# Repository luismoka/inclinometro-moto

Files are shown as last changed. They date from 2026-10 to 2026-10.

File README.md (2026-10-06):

# Inclinómetro para moto (MotoLean)

**Versión 3.2**

> **Nuevo:** versión para la placa Waveshare ESP32-S3-LCD-1.69 (pantalla de 1,69"), todavía sin probar en placa real. Ver [docs/PLACA_169.md](docs/PLACA_169.md). El resto de este documento describe la versión para la LOLIN S3 Mini Pro (firmware 2.3).

Inclinómetro casero para moto basado en una placa **LOLIN S3 Mini Pro** (ESP32-S3 con pantalla de 0,85" y sensor de movimiento integrado) y un GPS **NEO-6M**. Muestra la inclinación, la aceleración y la velocidad, graba las rutas y las enseña después sobre un mapa.

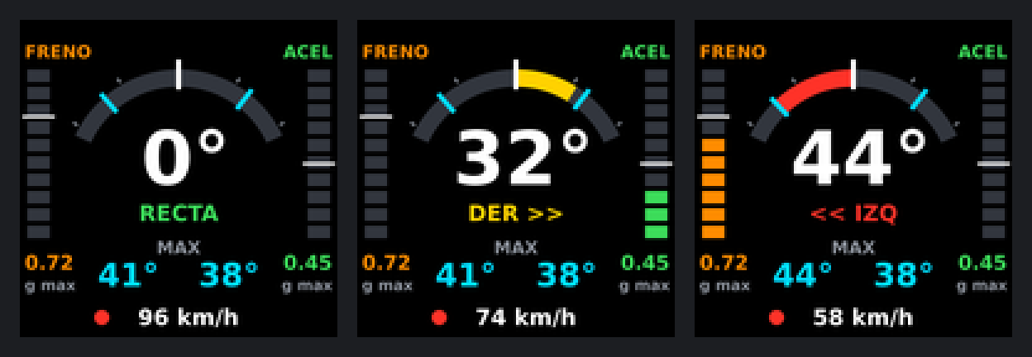
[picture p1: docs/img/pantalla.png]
Pantalla del inclinómetro


## Qué hace

- **Inclinación en directo**, con arco de color: azul hasta 25°, amarillo hasta 40°, rojo a partir de ahí.
- **Máxima inclinación** a izquierda y derecha.
- **Aceleración y frenada** en g, con barra en directo y máximo alcanzado.
- **Velocidad GPS** en pantalla y velocidad máxima.
- **Grabación de rutas**: posición, velocidad, inclinación, aceleración y frenada, un punto por segundo.
- **Mapa**: la ruta se ve después coloreada por inclinación o velocidad, con las frenadas y los acelerones marcados.
- **Web propia**: datos en directo, descarga de rutas y configuración desde el móvil o el ordenador, sin instalar ninguna app.
- **WiFi de casa**: en casa se une a la red doméstica y se entra en `http://motolean.local`.
- **Memoria**: máximos, calibración y rutas se conservan al apagar.
- **Montaje libre**: una calibración de dos pasos permite colocar la placa en cualquier posición.
- **Caja desmontable**: la base se queda en la moto y la electrónica se quita y se pone sin herramientas.

Sin GPS el inclinómetro funciona igual, sin velocidad ni rutas, y no hace falta soldar nada.

## Novedades de la versión 2.0

| Novedad | Dónde se explica |
|---|---|
| GPS: velocidad y grabación de rutas | [docs/GPS_Y_RUTAS.md](docs/GPS_Y_RUTAS.md) |
| Página de mapa para ver las rutas | [docs/WEB.md](docs/WEB.md) |
| Web ampliada: rutas y WiFi de casa | [docs/WEB.md](docs/WEB.md) |
| Caja desmontable con GPS | [docs/CAJA_GPS.md](docs/CAJA_GPS.md) |
| Pulsadores para la tapa | [docs/SOPORTE.md](docs/SOPORTE.md) |
| Cajas ajustadas con medidas de calibre | [docs/SOPORTE.md](docs/SOPORTE.md) |

El detalle completo está en el [CHANGELOG.md](CHANGELOG.md).

## Puesta en marcha

1. **Reunir el material**: [docs/MATERIALES.md](docs/MATERIALES.md).
2. **Cargar el firmware** ya compilado desde el navegador: [docs/CARGAR_FIRMWARE.md](docs/CARGAR_FIRMWARE.md).
3. **Soldar el GPS** (opcional): [docs/GPS_Y_RUTAS.md](docs/GPS_Y_RUTAS.md).
4. **Imprimir y montar la caja**: [docs/CAJA_GPS.md](docs/CAJA_GPS.md) con GPS, o [docs/SOPORTE.md](docs/SOPORTE.md) sin él.
5. **Calibrar y usar**: [docs/USO.md](docs/USO.md).

## Documentación

| Documento | Contenido |
|---|---|
| [docs/MATERIALES.md](docs/MATERIALES.md) | Lista de todo lo que se utiliza: componentes, tornillería, herramientas y programas |
| [docs/CARGAR_FIRMWARE.md](docs/CARGAR_FIRMWARE.md) | Cómo grabar el `.bin` en la placa sin instalar nada |
| [docs/USO.md](docs/USO.md) | Botones, calibración y pantalla |
| [docs/WEB.md](docs/WEB.md) | Páginas web de la placa y página del mapa |
| [docs/GPS_Y_RUTAS.md](docs/GPS_Y_RUTAS.md) | Conexión del GPS, grabación de rutas y WiFi de casa |
| [docs/CAJA_GPS.md](docs/CAJA_GPS.md) | Caja desmontable con GPS: base fija y módulo de quita y pon |
| [docs/SOPORTE.md](docs/SOPORTE.md) | Soporte sencillo sin GPS y pulsadores |
| [docs/FUNCIONAMIENTO.md](docs/FUNCIONAMIENTO.md) | Cómo se calcula la inclinación y qué limitaciones tiene |
| [docs/HARDWARE.md](docs/HARDWARE.md) | Pines y componentes de la placa |
| [docs/COMPILAR.md](docs/COMPILAR.md) | Cómo compilar el programa desde el código fuente |
| [CHANGELOG.md](CHANGELOG.md) | Historial de versiones |

## Estructura del repositorio

```
firmware/
  moto_inclinometro/   Código fuente (Arduino)
  bin/                 Firmware compilado, listo para grabar
soporte/               STL de las cajas y scripts que los generan
mapa/                  Página para ver una ruta grabada sobre el mapa
herramientas/          Scripts que generan las imágenes de la documentación
docs/                  Documentación e imágenes
```

## Estado del proyecto

| Parte | Estado |
|---|---|
| Inclinación, aceleración y pantalla | Cargado y funcionando en la placa. Pendiente de probar en marcha |
| GPS, rutas y WiFi de casa | Compilado; **sin probar** con el GPS conectado |
| Página del mapa | Probada con una ruta inventada; el fondo de mapa está pendiente de confirmar |
| Soporte sencillo (sin GPS) | Primera versión impresa; la versión corregida con medidas de calibre está sin imprimir |
| Caja desmontable con GPS | Diseñada; **sin imprimir** |
| Medida del manillar | Calculada (tubo de 28,6 mm), sin medir en la moto |

## Aviso de seguridad

Es un proyecto de aficionado y la medida es orientativa. No mires la pantalla en plena curva ni la uses como referencia para apurar la inclinación.

## Apoyar el proyecto

El proyecto es libre y gratuito. Si te ha sido útil y quieres invitarme a un café, puedes hacerlo en [paypal.me/luismoka](https://paypal.me/luismoka).

## Licencia

Proyecto publicado bajo licencia [MIT](LICENSE).

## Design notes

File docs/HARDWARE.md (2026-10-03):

# Hardware

## Placa: LOLIN S3 Mini Pro v1.1.0

| Característica | Valor |
|---|---|
| Microcontrolador | ESP32-S3FH4R2 (4 MB de flash, 2 MB de PSRAM) |
| Pantalla | TFT de 0,85", 128 × 128, ST7789 (existe otra versión con GC9A01) |
| Sensor de movimiento | QMI8658C, 6 ejes, por I2C |
| Botones | 3 |
| Medidas | 34,3 × 25,4 mm |
| Alimentación | 5 V por USB-C o por el pin 5V |

## Pines usados

| Función | Pin |
|---|---|
| I2C SDA | IO12 |
| I2C SCL | IO11 |
| Dirección I2C del sensor | `0x6B` |
| GPS: TX del módulo | IO13 |
| GPS: RX del módulo | IO14 |
| LED de colores: datos / alimentación | IO8 / IO7 |
| Botón azul | IO0 |
| Botón naranja | IO47 |
| Botón verde | IO48 |
| Pantalla: retroiluminación | IO33 |
| Pantalla: MOSI / SCK | IO38 / IO40 |
| Pantalla: CS / DC / RST | IO35 / IO36 / IO34 |

Los pines de la pantalla los fija la librería TFT_eSPI de WEMOS (archivo `Setup406_LOLIN_S3_MINI_PRO_ST7789.h`).

## Referencias

- [Documentación oficial de la S3 Mini Pro](https://www.wemos.cc/en/latest/s3/s3_mini_pro.html)
- [Ejemplo Arduino oficial](https://github.com/wemos/D1_mini_Examples/tree/master/examples/06.S3_MINI_PRO/s3_mini_pro)
- [TFT_eSPI de WEMOS](https://github.com/wemos/TFT_eSPI)

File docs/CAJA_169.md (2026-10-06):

# Caja para la placa Waveshare ESP32-S3-LCD-1.69

Caja desmontable para la placa de 1,69", el GPS con su antena y la botonera de dos botones. **Primera versión: todavía no se ha impreso ni probado.**

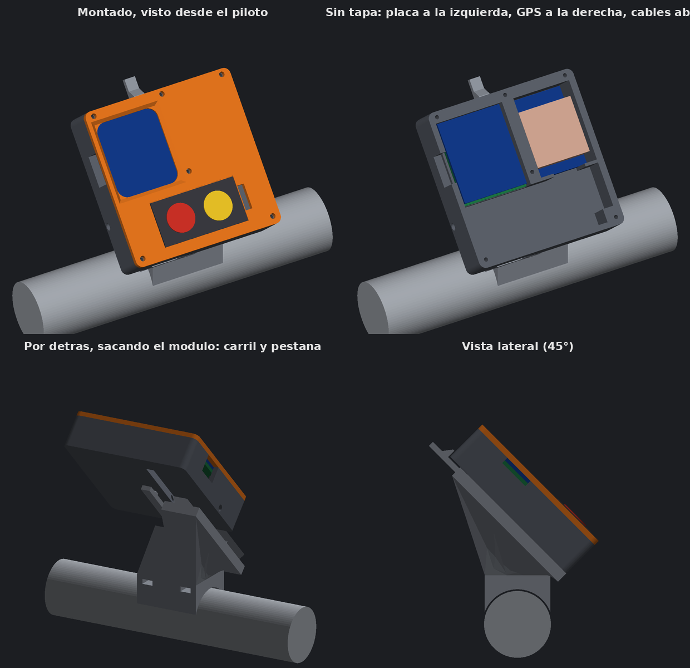
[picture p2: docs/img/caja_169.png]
Caja


## Piezas

| Archivo | Pieza | Cómo imprimirla |
|---|---|---|
| `soporte/caja_169/caja169_base.stl` | Base fija al manillar, con carril y pestaña | Como viene, con el carril hacia arriba; necesita soportes bajo el cuello |
| `soporte/caja_169/caja169_modulo.stl` | Módulo con placa, GPS y cables | Apoyado sobre su trasera, sin soportes |
| `soporte/caja_169/caja169_tapa.stl` | Tapa con ventana y asiento de la botonera | Con la cara interior sobre la cama, sin soportes |

Cada pieza tiene también su `.step` para abrirla y modificarla en Fusion, y `caja169_conjunto.step` trae las tres montadas.

Material: PETG. Medidas exteriores del módulo con tapa: 70 × 70,5 × 19,4 mm.

## Distribución (vista desde el piloto)

- **Arriba a la izquierda:** la placa, con el USB-C hacia la pared izquierda, que tiene una entrada para el cable.
- **Arriba a la derecha:** el GPS al fondo y la antena encima, bajo la tapa.
- **Abajo:** hueco de 25 mm para el mazo de 12 cables y el cable plano de la botonera.
- **Sobre la tapa, abajo:** asiento de 40,6 × 20,6 mm para pegar la botonera, y a su derecha una ranura de 3,2 × 11,2 mm por la que pasan el conector y el cable plano.

## Montaje

1. La placa apoya en cuatro pilares con un tetón de 1,2 mm que entra en cada taladro. La sujeta la tapa, que pisa el borde del cristal.
2. La tapa se cierra con seis tornillos autorroscantes de 2 mm.
3. El módulo entra deslizando de arriba abajo en el carril de la base hasta que salta la pestaña. Un tornillo M3 opcional lo bloquea por el lateral.
4. La base se sujeta al manillar con dos bridas.

## Pendiente de comprobar

- La posición vertical de la ventana supone que la imagen empieza 1,5 mm por debajo del borde superior de la placa.
- El manillar se ha supuesto de 28,6 mm, como en la caja anterior.

Para regenerar los archivos: `python3 soporte/generar_caja_169.py` (necesita `cadquery`, `trimesh` y `pillow`).

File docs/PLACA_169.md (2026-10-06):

# Versión para Waveshare ESP32-S3-LCD-1.69 (firmware 3.2)

Adaptación del inclinómetro a la placa **Waveshare ESP32-S3-LCD-1.69** (sin táctil): pantalla de 1,69" y 240×280 puntos, con el mismo sensor de movimiento QMI8658.

> **Estado: compila, pero todavía no se ha probado en una placa real.** Los puntos pendientes de comprobar están al final.

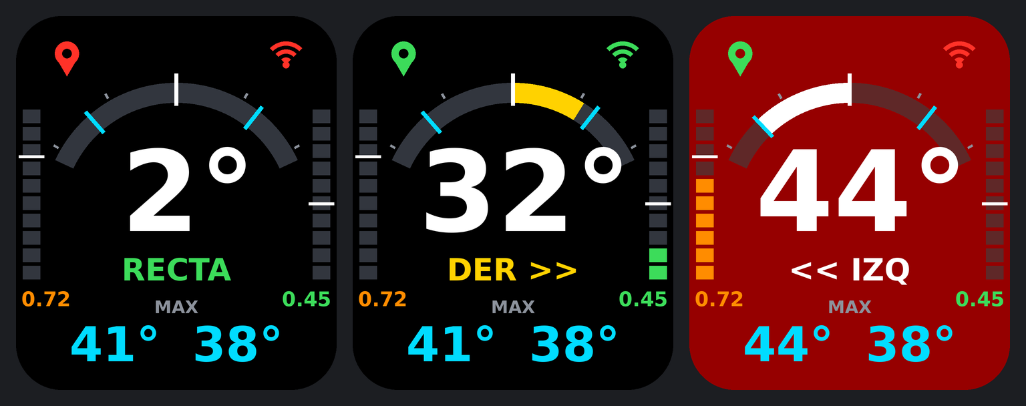
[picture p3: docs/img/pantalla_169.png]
Pantalla


## Pantalla

- **Número grande**: inclinación actual. Entre −4° y +4° la moto se considera **RECTA**.
- **Arco de color** y máximos a izquierda y derecha.
- **Barras laterales**: aceleración y frenada.
- **Fondo rojo parpadeante** al pasar de 40° de inclinación.
- **Icono GPS (arriba a la izquierda)**: rojo parpadeando sin señal, verde fijo con señal. 
- **REC (arriba en el centro)**: parpadea en rojo mientras se graba la ruta.
- **Icono WiFi (arriba a la derecha)**: gris sin conexión, verde cuando está unido a la WiFi de casa o hay un móvil conectado a la red `MotoLean`.
- La velocidad no se muestra en pantalla (sí se graba en la ruta).

## Botones (botonera externa)

Desde la versión 3.1 se maneja con una botonera de membrana de 2 botones (amarillo y rojo), para que la placa pueda ir en una caja cerrada.

| Botón | Pulsación | Acción |
|---|---|---|
| Amarillo | breve | Ajuste de centro: pone a cero con la moto recta. Solo se acepta si el desvío es menor de ±10° |
| Amarillo | 3 s | Calibración completa en dos pasos (amarillo confirma, rojo cancela) |
| Rojo | breve | Borrar los máximos |
| Rojo | 1,5 s | Terminar o reanudar la ruta |
| Los dos | 1,5 s | Girar la pantalla 180° |

Los botones BOOT y PWR de la placa siguen funcionando como reserva (BOOT breve gira, BOOT 3 s calibra, PWR breve centra, PWR 1,5 s ruta). Todo está también en la web, en `/ajustes`.

Los máximos se ponen a cero al empezar cada ruta, y siguen a la vista después de terminarla.

### Conexión de la botonera

Los tres hilos de la botonera van a **GPIO16, GPIO2 y GPIO3, en cualquier orden**. No hace falta saber cuál es el común: la primera vez que se pulsa un botón, la pantalla pide pulsar el amarillo y luego el rojo, y lo guarda. Se puede repetir desde `/ajustes` → *Configurar la botonera*.

## Cables del conector de 12 hilos

Contando desde el extremo del conector RTC:

| Nº | Señal | Color | Uso |
|---|---|---|---|
| 1 | GPIO18 | negro | RX del GPS |
| 2 | GPIO17 | rojo | TX del GPS |
| 3 | GPIO16 | verde | botonera |
| 4 | GPIO3 | amarillo | botonera |
| 5 | GPIO2 | negro | botonera |
| 6 | SDA (GPIO11) | rojo | libre |
| 7 | SCL (GPIO10) | marrón | libre |
| 8 | U0TXD | naranja | libre |
| 9 | U0RXD | verde | libre |
| 10 | 3V3 | azul | libre |
| 11 | GND | morado | GND del GPS |
| 12 | 5V | gris | VCC del GPS |

## Conexión del GPS (NEO-6M)

| GPS | Placa |
|---|---|
| VCC | 5V (solo hay tensión con el USB conectado; con batería, usar 3V3) |
| GND | GND |
| TX | GPIO17 |
| RX | GPIO18 |

## Cargar el firmware

Fichero: [`firmware/bin/MotoLean_169_firmware.bin`](../firmware/bin/MotoLean_169_firmware.bin)

1. Mantener pulsado **BOOT** mientras se conecta el USB.
2. Abrir <https://espressif.github.io/esptool-js/> en Chrome o Edge, pulsar *Connect* y elegir el puerto.
3. Dirección **0x0**, seleccionar el fichero y pulsar *Program*.
4. Desconectar y volver a conectar el USB.

**No vale el fichero `MotoLean_firmware.bin`**, que es el de la placa LOLIN.

## Compilar

Placa `ESP32S3 Dev Module`, USB CDC On Boot activado, Flash 16MB, partición `16M Flash (3MB APP/9.9MB FATFS)`, PSRAM `OPI`. En TFT_eSPI se usa la configuración [`Setup_Waveshare_169.h`](../firmware/moto_inclinometro_169/Setup_Waveshare_169.h).

```
arduino-cli compile --fqbn esp32:esp32:esp32s3:CDCOnBoot=cdc,FlashSize=16M,PartitionScheme=app3M_fat9M_16MB,PSRAM=opi firmware/moto_inclinometro_169
```

## Pendiente de comprobar en la placa

- Colores de la pantalla (orden de color e inversión). Si salen cambiados o en negativo se corrige en una línea.
- Botón PWR: se ha supuesto que da nivel alto al pulsarlo, según la documentación.
- El zumbador de la placa no se usa.
- Las cajas impresas del repositorio son para la LOLIN y no sirven para esta placa.

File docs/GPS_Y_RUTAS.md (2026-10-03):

# GPS, rutas y WiFi de casa

> Esta parte está compilada pero **todavía no se ha probado con el GPS conectado**.

## Conexión del GPS

Módulo **GY-GPS6MV2** (u-blox NEO-6M) con su antena cerámica. Los cuatro agujeros que usa están seguidos en el mismo borde de la placa:

| Módulo GPS | Placa S3 Mini Pro |
|---|---|
| VCC | 5V |
| GND | G |
| TX | 13 |
| RX | 14 |

La antena debe mirar al cielo y no tener metal encima. El NEO-6M tarda entre 30 segundos y varios minutos en tener señal al encender.

## Qué cambia en la pantalla

- Abajo aparece la **velocidad** en km/h, o «sin GPS» mientras no hay señal.
- Un **punto rojo** junto a la velocidad indica que se está grabando una ruta.

## LED de estado

El LED de colores de la placa indica el estado del GPS. Se ve por la mirilla de 3,5 mm de la tapa, a la derecha de la pantalla, en su mitad inferior.

| Color | Significado |
|---|---|
| Rojo | El GPS no contesta |
| Amarillo | Contesta, pero aún no tiene posición |
| Verde | Tiene posición |
| Verde con un guiño cada 2 s | Tiene posición y está grabando la ruta |
| Azul | Tiene posición, pero la grabación está parada a mano |

El brillo se ajusta con `LED_BRILLO` al principio del código. El módulo GPS tiene además su propio LED, que parpadea una vez por segundo cuando hay posición, pero queda tapado dentro de la caja.

## Grabación de rutas

- La ruta empieza sola cuando hay señal GPS y la moto pasa de 5 km/h.
- Se guarda un punto por segundo: hora, posición, velocidad, mayor inclinación del segundo y mayor aceleración y frenada del segundo.
- Parado más de 5 segundos deja de guardar puntos, para no gastar memoria.
- Cada vez que se enciende la placa se crea una ruta nueva.
- **Terminar la ruta a mano:** mantén el botón verde 1,5 s, o pulsa «Terminar ruta» en la página de rutas. La ruta queda guardada y la grabación parada (LED azul) hasta que repitas la pulsación o apagues y enciendas.
- Caben unas 19 horas en movimiento. Cuando falta sitio se borra la ruta más antigua.
- Los datos se vuelcan a la memoria cada 10 segundos: si se corta la corriente se pierden como mucho esos segundos.

## Descargar y ver una ruta

1. Entra en la página de la placa y pulsa **Rutas grabadas**.
2. Pulsa **Descargar** en la ruta: baja un archivo `.csv`.
3. Abre [`mapa/index.html`](../mapa/index.html) en un navegador con internet y carga ese archivo con **Abrir ruta**.

El mapa muestra el trazado coloreado por inclinación o por velocidad, marca las frenadas fuertes (desde 0,5 g) y los acelerones (desde 0,4 g), y resume distancia, tiempo, velocidades y máximos. Pulsando sobre el trazado se ven los datos de ese punto. En `mapa/ruta_de_ejemplo.csv` hay una ruta inventada para probarlo.

Columnas del archivo: `t_utc` (segundos desde 1970, hora UTC), `lat`, `lon`, `kmh`, `inclinacion` (grados, positivo a la derecha), `acel_max_g`, `acel_min_g`.

## WiFi de casa

La placa mantiene siempre su propia WiFi (`MotoLean`). Además puede entrar en la WiFi de casa para acceder a ella desde cualquier ordenador de la red:

1. Conéctate a `MotoLean`, abre <http://192.168.4.1> y pulsa **WiFi de casa**.
2. Escribe el nombre y la clave de tu WiFi y guarda. La placa se reinicia.
3. Desde un ordenador de casa entra en <http://motolean.local>. Si no responde, usa la dirección IP que muestra esa misma página o la lista de dispositivos del router.

Detalles:

- La WiFi de casa solo se busca durante los 15 primeros segundos tras encender. En ruta, pasado ese tiempo, la placa se queda solo con su propia red.
- Solo funciona con redes de 2,4 GHz.
- La clave se guarda en la memoria de la placa, no en el código ni en este repositorio.

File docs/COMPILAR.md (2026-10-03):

# Compilar desde el código fuente

Solo hace falta si se quiere modificar el programa. Para usarlo tal cual basta con [cargar el `.bin`](CARGAR_FIRMWARE.md).

## Con Arduino IDE

1. Instala Arduino IDE 2.
2. En *Herramientas → Placa → Gestor de placas*, instala **esp32** de Espressif.
3. Descarga la librería **TFT_eSPI de WEMOS** desde <https://github.com/wemos/TFT_eSPI> (*Code → Download ZIP*) y añádela con *Programa → Incluir biblioteca → Añadir biblioteca .ZIP*.
4. En la carpeta de esa librería, edita `User_Setup_Select.h`:
   - comenta `#include <User_Setup.h>`
   - descomenta `#include <User_Setups/Setup406_LOLIN_S3_MINI_PRO_ST7789.h>`
   - si la placa lleva pantalla GC9A01, usa `Setup404_LOLIN_S3_MINI_PRO.h` en su lugar.
5. Abre `firmware/moto_inclinometro/moto_inclinometro.ino`.
6. Elige la placa **LOLIN S3 Mini** (o **LOLIN S3 Mini Pro** si tu versión del paquete la incluye) y el puerto.
7. En *Herramientas*, pon **USB CDC On Boot: Enabled** para ver el puerto serie por USB.
8. Pulsa **Subir**. Si no aparece el puerto, conecta la placa con el botón azul pulsado.

## Entorno con el que se generó el `.bin` publicado

| Componente | Versión |
|---|---|
| arduino-cli | 1.1.1 |
| Paquete esp32 (Espressif) | 2.0.9 |
| Placa (FQBN) | `esp32:esp32:lolin_s3_mini:CDCOnBoot=cdc` (puerto serie por USB) |
| TFT_eSPI (WEMOS) | 2.5.44, con `Setup406` |

Comandos equivalentes:

```bash
arduino-cli compile -b esp32:esp32:lolin_s3_mini:CDCOnBoot=cdc --output-dir build firmware/moto_inclinometro

esptool.py --chip esp32s3 merge_bin -o MotoLean_firmware.bin \
  --flash_mode dio --flash_freq 80m --flash_size 4MB \
  0x0     build/moto_inclinometro.ino.bootloader.bin \
  0x8000  build/moto_inclinometro.ino.partitions.bin \
  0xe000  <paquete esp32>/tools/partitions/boot_app0.bin \
  0x10000 build/moto_inclinometro.ino.bin
```

No hacen falta más librerías: el sensor y el GPS se leen directamente, y el resto (WiFi, WebServer, Preferences, LittleFS, ESPmDNS, Wire) viene con el paquete esp32.

## Ajustes rápidos en el código

| Constante | Para qué sirve |
|---|---|
| `WIFI_NOMBRE`, `WIFI_CLAVE` | Red WiFi que crea la placa |
| `LEAN_MIN_REG`, `LEAN_MAX_REG` | Rango de inclinación que cuenta como máximo |
| `G_MAX_REG` | Aceleración máxima que se acepta como válida |
| `IMU_ADDR` | Dirección I2C del sensor |

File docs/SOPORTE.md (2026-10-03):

# Soporte de manillar

Soporte impreso en 3D para fijar la placa al centro del manillar con la pantalla inclinada 45° hacia el piloto. Diseñado para la Honda Africa Twin 1100 (2021), con tubo de 28,6 mm en la zona central.

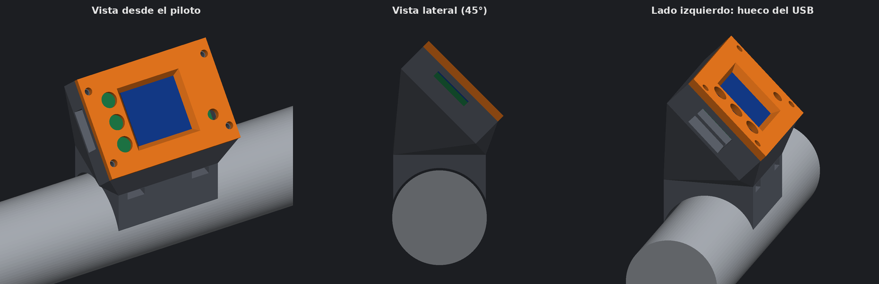
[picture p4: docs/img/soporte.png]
Soporte


> **Medida del manillar calculada, no medida.** El soporte está dimensionado para un tubo de **28,6 mm de diámetro** (más 0,7 mm de holgura para la goma), que es el valor estándar calculado para la zona central del manillar de la Africa Twin 1100. No se ha medido sobre la moto: comprueba el diámetro con un calibre antes de imprimir y, si es distinto, cambia `RB` en `soporte/generar_soporte.py` y regenera los STL.

> Las imágenes son vistas del modelo 3D. **El soporte aún no se ha impreso ni probado.** Cuando esté impreso, las fotos reales deben ir en `docs/img/`.

## Piezas

| Archivo | Pieza |
|---|---|
| [`soporte/soporte_cuerpo.stl`](../soporte/soporte_cuerpo.stl) | Base de apoyo al manillar, cuello a 45° y caja de la placa |
| [`soporte/soporte_tapa.stl`](../soporte/soporte_tapa.stl) | Tapa con ventana para la pantalla y agujeros de los botones |
| [`soporte/soporte_pulsadores_x3.stl`](../soporte/soporte_pulsadores_x3.stl) | Los tres pulsadores, colocados para imprimir juntos |
| [`soporte/soporte_pulsador.stl`](../soporte/soporte_pulsador.stl) | Un pulsador suelto, por si hay que repetir alguno |

## Medidas principales

| Elemento | Medida |
|---|---|
| Tamaño total | 44 × 32 × 47 mm aprox. |
| Tubo de manillar | 28,6 mm (valor calculado, sin medir en la moto), con 0,7 mm de holgura para una goma |
| Ancho ocupado en el tubo | 34 mm |
| Túneles para bridas | 2, para bridas de hasta 4,8 mm |
| Hueco de la placa | 35,2 × 26,2 mm, 7,45 mm de fondo, con dos apoyos de 3,4 mm en el extremo de la pantalla |
| Ventana de pantalla | 17,7 × 16,5 mm por dentro, con los bordes en bisel |
| Agujeros de botones | 3 de 5,0 mm, separados 7,1 mm y centrados en la placa |
| Pulsadores | Vástago de 4,6 mm que sobresale 3 mm; ala interior de 6,4 × 0,8 mm |
| Hueco del USB-C | 13 × 6,5 mm, en el lateral izquierdo |
| Tornillos de la tapa | 4 × M2, agujero de 1,8 mm en el cuerpo y 2,4 mm en la tapa |

La placa va apaisada, con los botones a la izquierda y el cable USB saliendo por ese mismo lado.

## Medidas sin confirmar

- **Ventana y botones**: recolocados con medidas de calibre (placa de 34,50 × 25,43 mm, cristal de 17,63 × 21,38 mm, botones cada 7,1 mm). La distancia de los botones al borde (2,9 mm) sigue saliendo de fotos. Esta tapa corregida está pendiente de imprimir y probar.
- **USB**: su posición se tomó de fotos de la placa junto a una regla, con un error de alrededor de 1 mm.
- **Fondo del hueco**: sale de medidas de calibre (conector USB 3,35 mm, cristal 1,85 mm y punta de los botones 2,03 mm sobre la placa blanca). El grosor de la placa (1,7 mm) está deducido, no medido, por eso se dejan 0,5 mm de holgura sobre el cristal.
- **Diámetro del manillar**: se usa el valor estándar de 28,6 mm, sin medirlo en la moto.

Por eso conviene **imprimir primero solo la tapa** y presentarla sobre la placa antes de imprimir el cuerpo.

## Impresión

| Parámetro | Valor orientativo |
|---|---|
| Material | PETG (aguanta sol y calor mejor que el PLA) |
| Altura de capa | 0,2 mm |
| Perímetros | 3–4 |
| Relleno | 30–40 % |
| Tapa | Plana sobre la cama, sin soportes |
| Cuerpo | Necesita soportes en el arco del manillar y en los túneles de las bridas |

## Montaje

1. Presenta la tapa sobre la placa y comprueba que ventana y agujeros coinciden.
2. Mete la placa en el cuerpo, con el USB hacia el hueco lateral izquierdo.
3. Cierra la tapa con los 4 tornillos M2.
4. Coloca una tira de goma de 0,5–1 mm entre la base y el manillar.
5. Sujeta con dos bridas pasadas por los túneles.
6. Con todo montado, [calibra](USO.md#calibración) y endereza la imagen con el botón verde.

## Pulsadores

Cada pulsador tiene forma de seta: el vástago asoma por el agujero de la tapa y el ala queda por dentro, así que no puede salirse. Van sueltos, sin tornillos ni pegamento.

La tapa queda a 0,5 mm del cristal y tiene por dentro un rebaje de 0,73 mm sobre los botones. Ahí se aloja el ala de 0,8 mm de cada pulsador, con 0,25 mm de juego para que el botón no quede apretado al cerrar.

- Se imprimen con el ala apoyada en la cama, sin soportes.
- Para montarlos, pon la tapa boca abajo, mete los tres vástagos en sus agujeros desde dentro y coloca el cuerpo encima antes de darle la vuelta.
- Si rozan en el agujero, repasa el vástago con una lija fina.

Pendientes de imprimir y probar.

## Pendiente

- **Estanqueidad**: la ventana está abierta. Para lluvia hay que pegar una lámina transparente por dentro y sellar la salida del cable.

## Modificar el diseño

El soporte se genera con [`soporte/generar_soporte.py`](../soporte/generar_soporte.py). Las medidas están al principio del archivo.

```bash
pip install trimesh manifold3d numpy pillow
python3 soporte/generar_soporte.py     # desde la raíz del repositorio
```

Regenera los dos STL y la imagen `docs/img/soporte.png`.

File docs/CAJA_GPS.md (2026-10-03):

# Caja desmontable con GPS

Caja para llevar juntas la placa, el GPS y la antena, en dos partes: una **base** que se queda en la moto y un **módulo** con la electrónica que se quita y se pone sin herramientas.

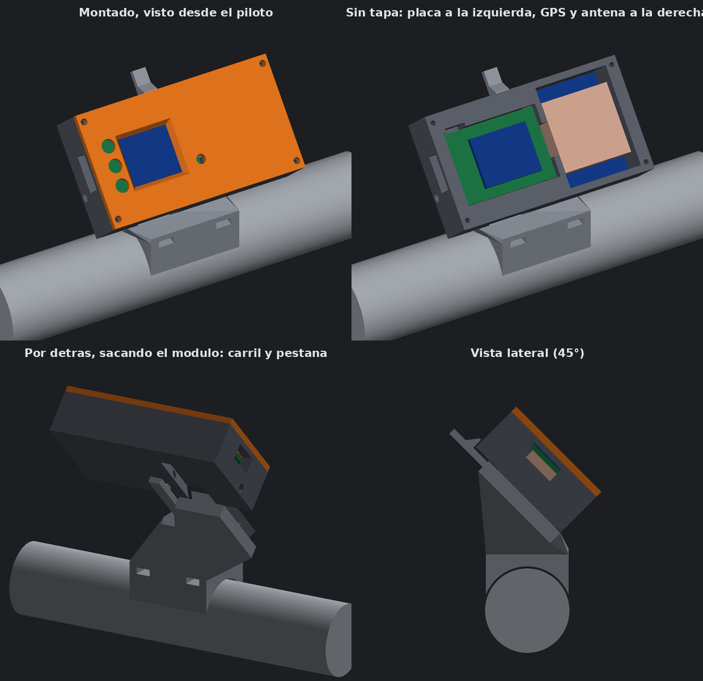
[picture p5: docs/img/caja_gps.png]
Caja con GPS


> Las imágenes son vistas del modelo 3D. **Esta caja aún no se ha impreso ni probado.**

## Piezas

| Archivo | Pieza | Cómo imprimirla |
|---|---|---|
| [`soporte/gps_base.stl`](../soporte/gps_base.stl) | Base de manillar con carril y pestaña de cierre | Con el carril hacia arriba (así viene); necesita soportes debajo |
| [`soporte/gps_modulo.stl`](../soporte/gps_modulo.stl) | Módulo con los huecos de placa, GPS y antena | Apoyado sobre su trasera, sin soportes |
| [`soporte/gps_tapa.stl`](../soporte/gps_tapa.stl) | Tapa con ventana y agujeros de botones | Plana, sin soportes |
| [`soporte/soporte_pulsadores_x3.stl`](../soporte/soporte_pulsadores_x3.stl) | Pulsadores | Los mismos del soporte sencillo |

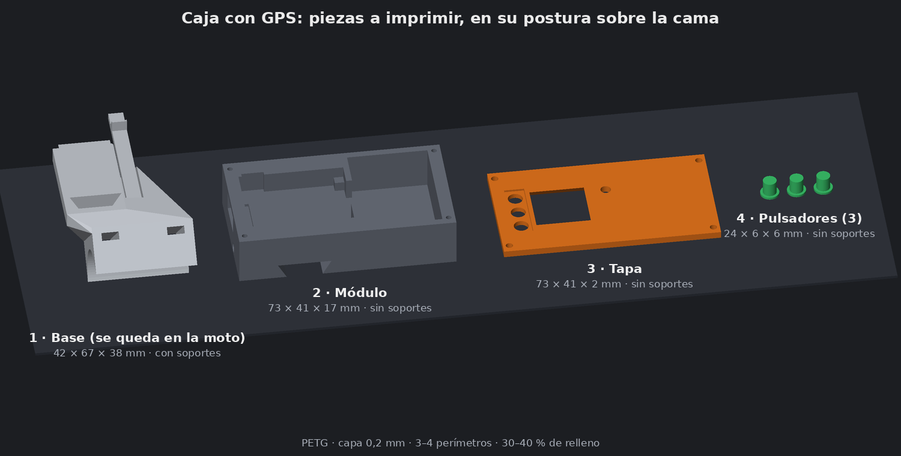
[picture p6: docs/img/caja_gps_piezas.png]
Piezas a imprimir


## Cómo se engancha

- El módulo tiene una ranura en cola de milano en la trasera y la base un carril con la misma forma.
- Se mete **de arriba abajo** hasta que hace tope. El peso y los baches lo empujan hacia el tope, no hacia fuera.
- Al llegar al tope, una **pestaña** de la base salta sobre el borde superior del módulo y lo bloquea.
- Para sacarlo: empuja la pestaña hacia atrás con el pulgar y tira del módulo hacia arriba. Antes hay que desenchufar el USB.
- **Seguro opcional:** un agujero de 3,4 mm atraviesa el módulo y el carril por el lado izquierdo. Con un tornillo M3 de 30 mm, o una brida fina, el módulo no puede salir aunque fallara la pestaña.

## Distribución interior

| Zona | Medidas del hueco | Contenido |
|---|---|---|
| Izquierda | 35,2 × 26,2 mm, 7,45 mm de fondo, con apoyos para que la placa quede recta | Placa principal, con los botones a la izquierda y el USB saliendo por el lateral izquierdo |
| Derecha | 27 × 36 mm, 15 mm de fondo | Placa del GPS al fondo y la antena encima, pegada a la tapa |
| Entre ambas | Paso de 12 mm | Los 4 cables del GPS |

Tamaño del módulo con tapa: 73 × 40,8 × 19,4 mm. El módulo queda centrado sobre el manillar y la pantalla a 45° hacia el piloto.

## Medidas usadas

| Pieza | Medida (calibre) |
|---|---|
| Placa del GPS | 35,44 × 26,41 × 4,03 mm, sin contar los pines |
| Antena | 25,08 × 25,14 × 9,00 mm |
| Placa principal | 34,50 × 25,43 mm |
| Manillar | 28,6 mm, valor calculado, sin medir en la moto |

## Antes de montar

- **Pines del GPS:** el hueco no deja sitio para la tira de pines. Hay que desoldarla o cortarla y soldar los cables directamente.
- **Antena:** va tumbada sobre la placa del GPS, con la cara cerámica hacia la tapa. Conviene fijarla con cinta de doble cara de espuma para que no vibre.
- **Cable de antena:** queda recogido dentro de la zona derecha.

## Dudas abiertas

- La antena queda inclinada 45° como la pantalla, no horizontal. Debería recibir bien, pero no está probado.
- Holgura del carril de 0,3 mm por lado: puede salir justa o floja según la impresora.
- La pestaña trabaja a flexión y se imprime inclinada; si se rompe o queda blanda habrá que engordarla.

## Modificar el diseño

```bash
pip install trimesh manifold3d numpy pillow
python3 soporte/generar_caja_gps.py     # desde la raíz del repositorio
```

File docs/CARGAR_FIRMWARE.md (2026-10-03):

# Cargar el firmware en la placa

El archivo [`firmware/bin/MotoLean_firmware.bin`](../firmware/bin/MotoLean_firmware.bin) contiene el programa completo (arranque, tabla de particiones y aplicación en un solo archivo). Se graba desde el navegador, sin instalar Arduino ni controladores.

## Qué necesitas

- Un ordenador con **Chrome o Edge** (Firefox y Safari no sirven: no tienen acceso al puerto serie).
- Un cable USB-C **de datos** (algunos cables solo cargan).

## Pasos

1. Descarga `MotoLean_firmware.bin`.
2. Mantén pulsado el **botón azul (IO0)** de la placa mientras la conectas por USB, y suéltalo después. Así entra en modo de carga.
3. Abre <https://espressif.github.io/esptool-js/>.
4. Pulsa **Connect** y elige el puerto que aparezca ("USB JTAG/serial debug unit" o "COM…").
5. En **Flash Address** escribe `0x0`.
6. Elige el archivo `MotoLean_firmware.bin` y pulsa **Program**.
7. Cuando termine, desconecta y vuelve a conectar el USB.

La pantalla debe mostrar **"SIN CALIBRAR – Mantén AZUL 3 s"** la primera vez.

> No pulses **Erase Flash** al actualizar: borraría la calibración y los máximos guardados.

## Si algo falla

| Síntoma | Causa probable | Solución |
|---|---|---|
| No aparece ningún puerto | La placa no está en modo de carga, o el cable es solo de carga | Repite el paso 2 o cambia de cable |
| Pantalla negra o colores raros | La placa lleva la otra pantalla (GC9A01) | Compilar con `Setup404_LOLIN_S3_MINI_PRO.h`, ver [COMPILAR.md](COMPILAR.md) |
| "ERROR – No encuentro el sensor IMU" | El sensor no responde en la dirección `0x6B` | Revisar `IMU_ADDR` en el código y recompilar |
| Se queda en "Connecting…" | El puerto está ocupado por otro programa | Cierra Arduino IDE u otros monitores serie |

## Datos del archivo

| Dato | Valor |
|---|---|
| Dirección de grabado | `0x0` |
| Chip | ESP32-S3, flash de 4 MB |
| Modo y frecuencia de flash | DIO, 80 MHz |
| Contenido | bootloader (`0x0`), particiones (`0x8000`), boot_app0 (`0xE000`), aplicación (`0x10000`) |

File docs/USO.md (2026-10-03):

# Uso

## Botones

Se identifican por el color de la serigrafía de la placa.

| Botón | Pulsación | Acción |
|---|---|---|
| Azul (IO0) | Mantener 3 s | Iniciar la calibración |
| Naranja (IO47) | Mantener 1,5 s | Borrar los máximos |
| Naranja (IO47) | Corta | Confirmar cada paso de la calibración |
| Verde (IO48) | Corta | Girar la pantalla 90° (queda guardado) |
| Verde (IO48) | Mantener 1,5 s | Terminar la ruta y parar la grabación; otra vez para reanudarla |

Durante la calibración, una pulsación corta del botón azul la cancela.

## Calibración

Se hace **una vez, con la placa ya fijada en la moto**, y se repite solo si se cambia de sitio.

1. Mantén el botón azul 3 s.
2. **Paso 1/2**: pon la moto **recta y quieta** (en el caballete central o sujetándola vertical) y pulsa naranja.
3. **Paso 2/2**: apóyala en la **pata de cabra** y pulsa naranja.

Con las dos posiciones el aparato deduce dónde está "arriba" y hacia dónde es "delante", sea cual sea la orientación de la placa. Se da por hecho que la pata de cabra está a la **izquierda**.

Si entre los dos pasos hay menos de unos 4° de diferencia aparece "ERROR – Poca diferencia" y hay que repetir.

## Pantalla

Pantalla

| Elemento | Significado |
|---|---|
| Arco superior | Inclinación actual, desde el centro hacia el lado al que se tumba. Fondo de escala ±65° |
| Marcas cian en el arco | Máxima inclinación alcanzada a cada lado |
| Número grande | Inclinación actual en grados |
| MAX | Máxima a la izquierda y a la derecha |
| Barra izquierda (FRENO) | Frenada en directo; cada segmento es 0,1 g. La raya blanca es el máximo |
| Barra derecha (ACEL) | Aceleración en directo, igual que la anterior |
| Cifra inferior | Velocidad GPS en km/h, o «sin GPS». Un punto rojo al lado indica que se está grabando la ruta |

## Web

Las páginas de la placa y la del mapa se explican en [WEB.md](WEB.md). Para entrar desde el móvil:

1. Conéctate a la WiFi **`MotoLean`** (clave `moto1234`).
2. Abre <http://192.168.4.1> en el navegador.

La página muestra los mismos datos en directo y tiene un botón para borrar los máximos. El nombre y la clave de la WiFi se cambian al principio del código (`WIFI_NOMBRE`, `WIFI_CLAVE`).

## Qué se guarda

| Dato | Cuándo |
|---|---|
| Calibración | Al terminarla |
| Giro de pantalla | Al cambiarlo |
| Máximos | Automáticamente, como mucho cada 5 s y solo si han cambiado |

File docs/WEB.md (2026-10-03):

# Web

El proyecto tiene dos partes web: las páginas que sirve la propia placa y la página del mapa, que se abre en un ordenador.

## Cómo entrar en la placa

| Situación | Red WiFi | Dirección |
|---|---|---|
| En cualquier sitio | `MotoLean` (clave `moto1234`) | <http://192.168.4.1> |
| En casa, con la WiFi de casa configurada | La de casa | <http://motolean.local> |

Hay que escribir `http://` delante: con `https` no funciona. Si el móvil avisa de que la red `MotoLean` no tiene internet, es normal; hay que elegir mantener la conexión.

## Páginas de la placa

### Inicio (`/`)

Datos en directo, actualizados cuatro veces por segundo:

- Inclinación actual y lado.
- Máxima a izquierda y derecha.
- Máxima aceleración y frenada.
- Velocidad y velocidad máxima.
- Aceleración en directo.
- Estado del GPS y si se está grabando una ruta.
- Botón para borrar los máximos.
- Enlaces a **Rutas grabadas** y **WiFi de casa**.

### Rutas grabadas (`/rutas`)

Lista de las rutas guardadas, con fecha y hora (UTC), minutos en movimiento y memoria libre. Cada ruta se puede **descargar** en CSV o **borrar**. Un enlace permite **terminar la ruta** en curso y parar la grabación, o reanudarla.

### WiFi de casa (`/wifi`)

Formulario para escribir el nombre y la clave de la WiFi doméstica. Al guardar, la placa se reinicia. Dejando el nombre vacío deja de usarla. Los detalles están en [GPS_Y_RUTAS.md](GPS_Y_RUTAS.md#wifi-de-casa).

### Diagnóstico del GPS (`/gps`)

Dice si el módulo GPS contesta: bytes y frases recibidos, satélites en uso, posición y las últimas frases tal como llegan. Se actualiza sola cada 2 segundos.

| Lo que muestra | Qué significa |
|---|---|
| No llega nada | Sin alimentación, o el TX del GPS no está en el 13 |
| Llegan datos pero no se entienden | Mal contacto u otra velocidad de comunicación |
| Contesta, sin posición | Funciona; le falta ver el cielo o más tiempo |
| Contesta y tiene posición | Todo correcto |

Las mismas frases salen también por el puerto serie USB, a 115200 baudios.

### Direcciones internas

| Dirección | Qué devuelve |
|---|---|
| `/datos` | Los datos en directo, en JSON |
| `/reset` | Borra los máximos |
| `/ruta?f=NOMBRE` | Una ruta en CSV |
| `/borrar?f=NOMBRE` | Borra una ruta |

## Página del mapa

Archivo [`mapa/index.html`](../mapa/index.html). Se abre con doble clic en un ordenador con internet; no hay que instalar nada.

1. Pulsa **Abrir ruta (.csv)** y elige un archivo descargado de la placa.
2. Elige el color del trazado: por **inclinación** o por **velocidad**.
3. Pulsa sobre el trazado para ver hora, velocidad, inclinación, aceleración y frenada de ese punto.

Qué muestra:

- **Resumen**: fecha, distancia, tiempo en movimiento, velocidad máxima y media, inclinación máxima a cada lado, y máxima aceleración y frenada.
- **Trazado**: gris, azul, amarillo y rojo, con los mismos umbrales que la pantalla de la placa (10°, 25° y 40°), o por tramos de velocidad (50, 90 y 120 km/h).
- **Marcas**: naranja en las frenadas desde 0,5 g y verde en los acelerones desde 0,4 g.
- **Fondo**: tres mapas a elegir arriba a la derecha (IGN España, calles de Esri y satélite de Esri).

En `mapa/ruta_de_ejemplo.csv` hay una ruta inventada para probar la página.

> El fondo de mapa está pendiente de confirmar: los servidores de OpenStreetMap y CARTO rechazaron la página abierta desde un archivo local, y los fondos actuales no se han podido comprobar todavía.

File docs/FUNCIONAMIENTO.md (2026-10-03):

# Cómo funciona

## El problema de medir la inclinación en una moto

En parado, un acelerómetro mide la inclinación sin problema: basta ver hacia dónde apunta la gravedad. En curva no sirve. Una moto tumbada en equilibrio nota la suma de gravedad y fuerza centrífuga exactamente alineada con su eje vertical, así que el acelerómetro "cree" que va recta.

Por eso la inclinación se calcula con el **giroscopio**, integrando la velocidad de giro alrededor del eje longitudinal de la moto. El giroscopio acumula un pequeño error con el tiempo (deriva), y ese error se corrige con el acelerómetro **solo cuando la moto va recta o está parada**, que es cuando el acelerómetro sí dice la verdad.

## Pasos del cálculo

1. **Lectura** del sensor QMI8658 a unas 235 muestras por segundo: acelerómetro (±8 g) y giroscopio (±512 °/s).
2. **Cambio de ejes**: con la calibración, las lecturas se pasan a los ejes de la moto (arriba, delante, izquierda).
3. **Integración** del giro alrededor del eje "delante" para obtener la inclinación.
4. **Corrección de deriva** cuando se cumplen a la vez: aceleración total cercana a 1 g, casi sin giro de guiñada ni cabeceo, y casi sin velocidad de balanceo.
5. **Aceleración longitudinal**: componente del acelerómetro (filtrado a 0,25 s) sobre el eje "delante".

## Registro de máximos

| Máximo | Condición para registrarlo |
|---|---|
| Inclinación | Entre 8° y 70°, y solo si el acelerómetro no coincide con el ángulo. Así se descartan la moto apoyada en la pata o tumbada en parado |
| Aceleración y frenada | Valores por debajo de 2 g, para descartar golpes |

Estos límites están al principio del código (`LEAN_MIN_REG`, `LEAN_MAX_REG`, `G_MAX_REG`).

## Limitaciones

- **Precisión orientativa**, de unos pocos grados.
- **Curvas largas y enlazadas**: al no haber tramos rectos, la deriva no se corrige y puede acumularse algo de error, que desaparece al volver a ir recto.
- **Cuestas**: la aceleración longitudinal incluye la componente de la gravedad, así que una pendiente fuerte suma o resta a la lectura.
- **Vibraciones**: un montaje rígido falsea sobre todo la aceleración. Conviene interponer goma.
- **Ancho de neumático**: se mide la inclinación del chasis, no el ángulo real respecto al punto de contacto.

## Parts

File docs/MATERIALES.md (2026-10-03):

# Materiales

Lista de todo lo que se utiliza en el proyecto.

## Electrónica

| Cantidad | Pieza | Detalle |
|---|---|---|
| 1 | Placa LOLIN (WEMOS) S3 Mini Pro v1.1.0 | ESP32-S3 con pantalla de 0,85" (versión ST7789), sensor de movimiento QMI8658 y 3 botones |
| 1 | Módulo GPS GY-GPS6MV2 | u-blox NEO-6M, con su antena cerámica de 25 × 25 mm y el cable que trae |
| 4 | Cables finos de unos 8 cm | Para unir el GPS a la placa (VCC, GND, TX, RX) |
| 1 | Cable USB-C de datos | Para cargar el firmware y para alimentar la placa en la moto |
| 1 | Toma USB de 5 V en la moto | Alimentación |

El GPS es opcional: sin él no hay velocidad ni rutas.

## Caja y fijación

| Cantidad | Pieza | Detalle |
|---|---|---|
| — | Filamento PETG | Aguanta sol y calor mejor que el PLA |
| 4 | Tornillos M2 × 8–10 mm | Cierran la tapa; roscan directamente en el plástico |
| 1 | Tornillo M3 × 30 mm o brida fina | Seguro opcional del módulo desmontable |
| 2 | Bridas de hasta 4,8 mm de ancho | Sujetan la base al manillar |
| 1 | Tira de goma de 0,5–1 mm | Entre la base y el manillar: evita que resbale y amortigua vibraciones |
| 1 | Cinta de doble cara de espuma | Fija la antena dentro de la caja |
| 1 | Lámina transparente (opcional) | Para cerrar la ventana de la pantalla frente a la lluvia |

## Piezas impresas

Caja desmontable con GPS:

| Archivo | Pieza |
|---|---|
| `soporte/gps_base.stl` | Base de manillar con carril y pestaña |
| `soporte/gps_modulo.stl` | Módulo de la electrónica |
| `soporte/gps_tapa.stl` | Tapa |
| `soporte/soporte_pulsadores_x3.stl` | Tres pulsadores |

Soporte sencillo, sin GPS:

| Archivo | Pieza |
|---|---|
| `soporte/soporte_cuerpo.stl` | Cuerpo |
| `soporte/soporte_tapa.stl` | Tapa |
| `soporte/soporte_pulsadores_x3.stl` | Tres pulsadores |

## Herramientas

- Impresora 3D y laminador (en este proyecto, Bambu Studio).
- Soldador y estaño, para el GPS.
- Calibre, para comprobar medidas.
- Destornillador pequeño.
- Ordenador con Chrome o Edge, para cargar el firmware.

## Programas y servicios

| Para qué | Qué se usa |
|---|---|
| Cargar el firmware | [esptool-js](https://espressif.github.io/esptool-js/), desde el navegador |
| Compilar el firmware | arduino-cli 1.1.1 o Arduino IDE 2, con el paquete esp32 de Espressif 2.0.9 |
| Pantalla | Librería [TFT_eSPI de WEMOS](https://github.com/wemos/TFT_eSPI) 2.5.44 |
| WiFi, web, memoria, rutas y `motolean.local` | Librerías incluidas en el paquete esp32: WiFi, WebServer, Preferences, LittleFS, ESPmDNS, Wire |
| Mapa | [Leaflet](https://leafletjs.com) 1.9.4 |
| Fondos del mapa | IGN España (CC BY 4.0, ign.es) y Esri |
| Diseño de las cajas | Python con trimesh, manifold3d y numpy |
| Imágenes de la documentación | Python con Pillow |

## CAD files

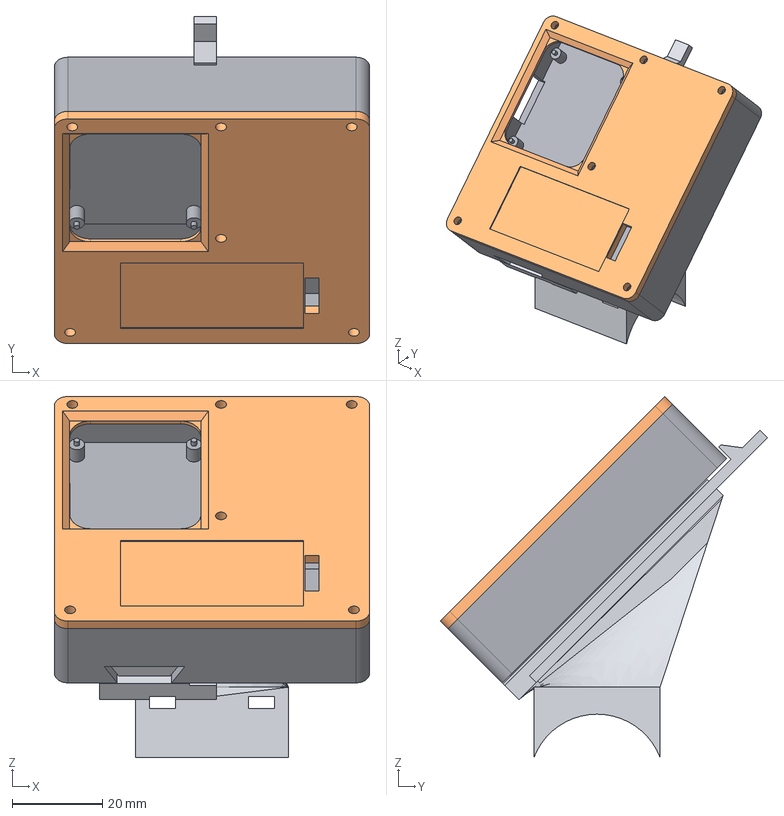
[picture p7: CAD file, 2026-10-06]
soporte/caja_169/caja169_conjunto.step
70.0 x 72.6 x 80.1 mm
modulo
tapa
base

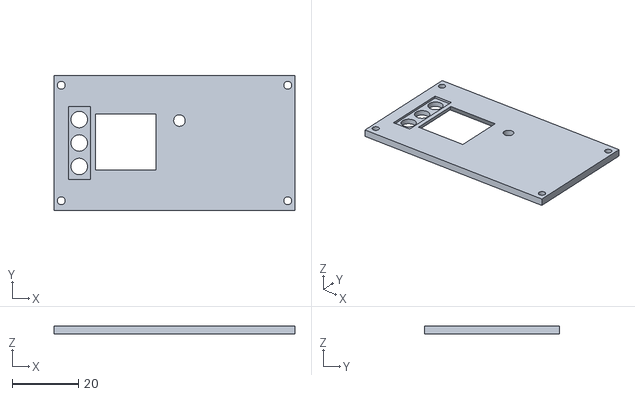
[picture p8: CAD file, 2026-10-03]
soporte/gps_tapa.stl
73.0 x 40.8 x 2.40

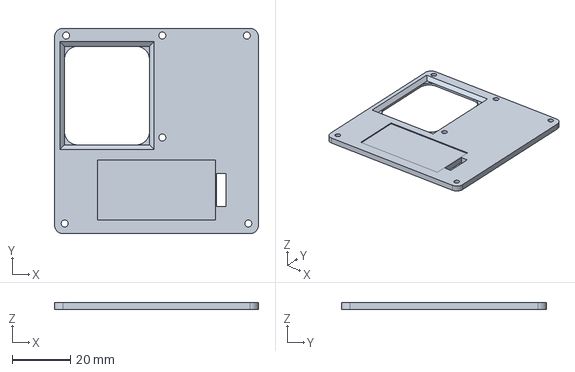
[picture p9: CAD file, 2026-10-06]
soporte/caja_169/caja169_tapa.step
70.0 x 70.5 x 2.40 mm

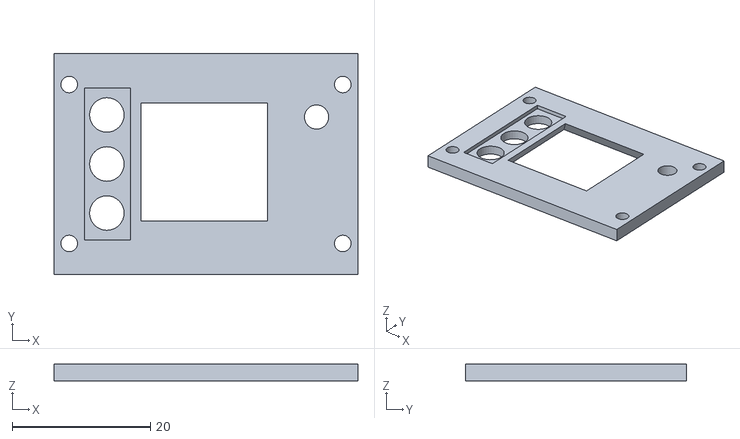
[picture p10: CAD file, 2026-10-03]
soporte/soporte_tapa.stl
44.0 x 32.0 x 2.40

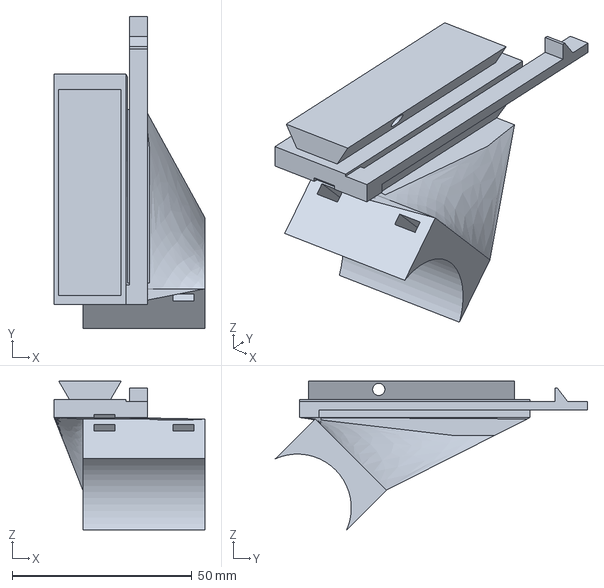
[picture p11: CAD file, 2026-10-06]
soporte/caja_169/caja169_base.step
42.0 x 86.8 x 41.4 mm

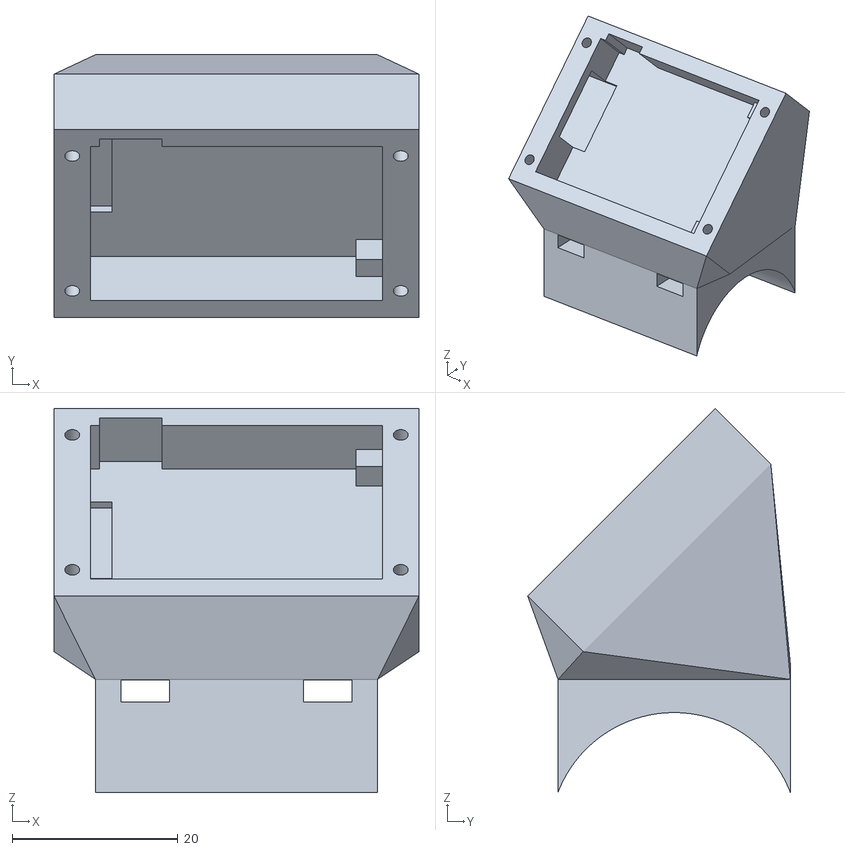
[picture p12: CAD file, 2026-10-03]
soporte/soporte_cuerpo.stl
44.0 x 31.7 x 46.3

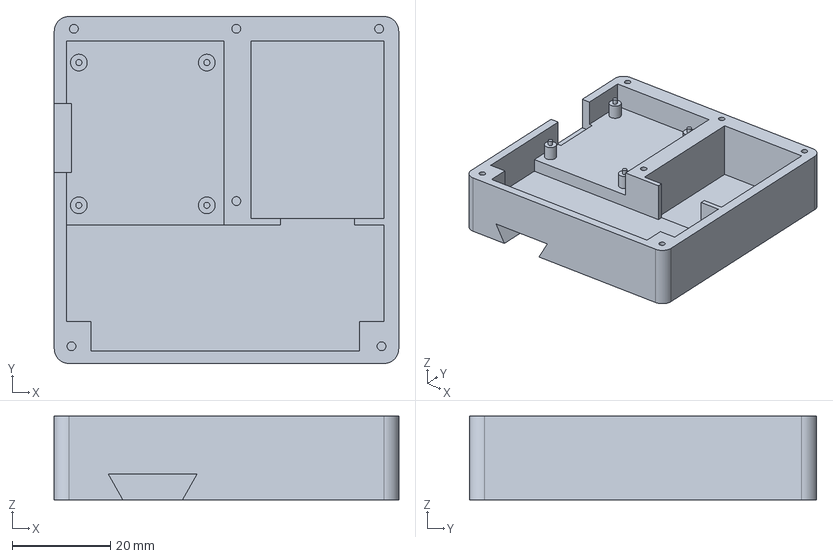
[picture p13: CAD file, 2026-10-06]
soporte/caja_169/caja169_modulo.step
70.0 x 70.5 x 17.0 mm

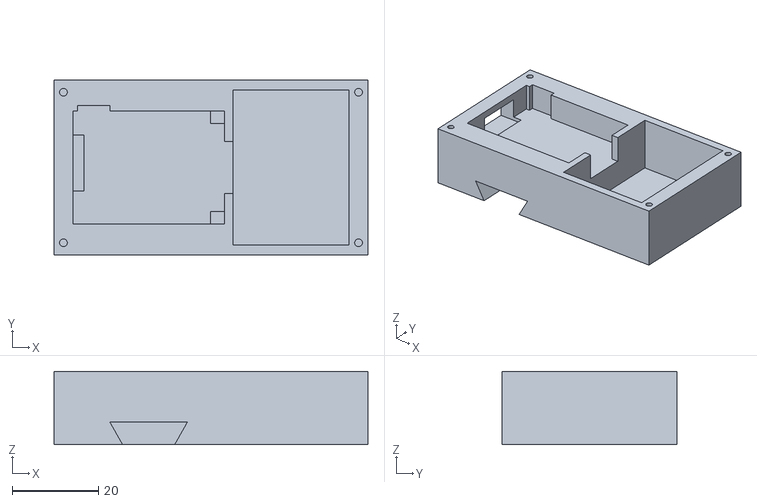
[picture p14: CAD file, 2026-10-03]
soporte/gps_modulo.stl
73.0 x 40.8 x 17.0

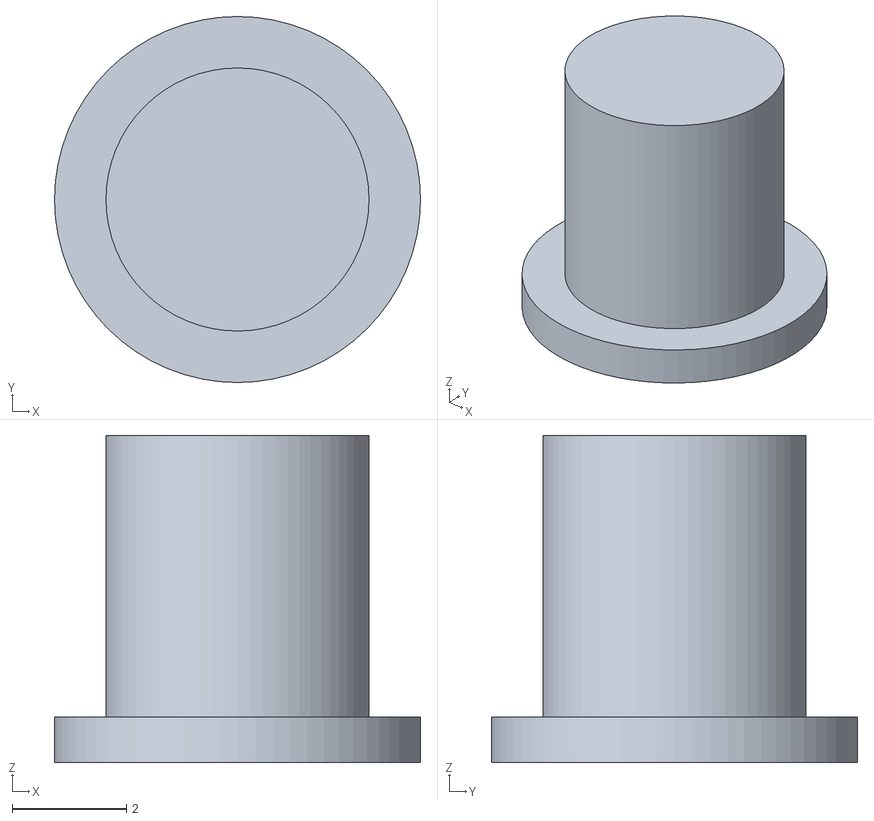
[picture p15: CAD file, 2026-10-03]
soporte/soporte_pulsador.stl
6.40 x 6.40 x 5.72

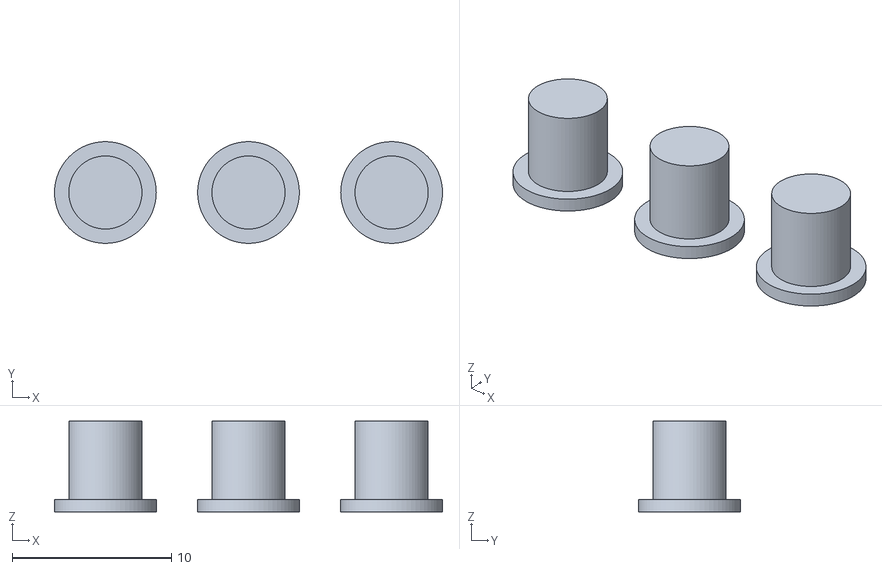
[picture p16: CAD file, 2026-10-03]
soporte/soporte_pulsadores_x3.stl
24.4 x 6.40 x 5.72

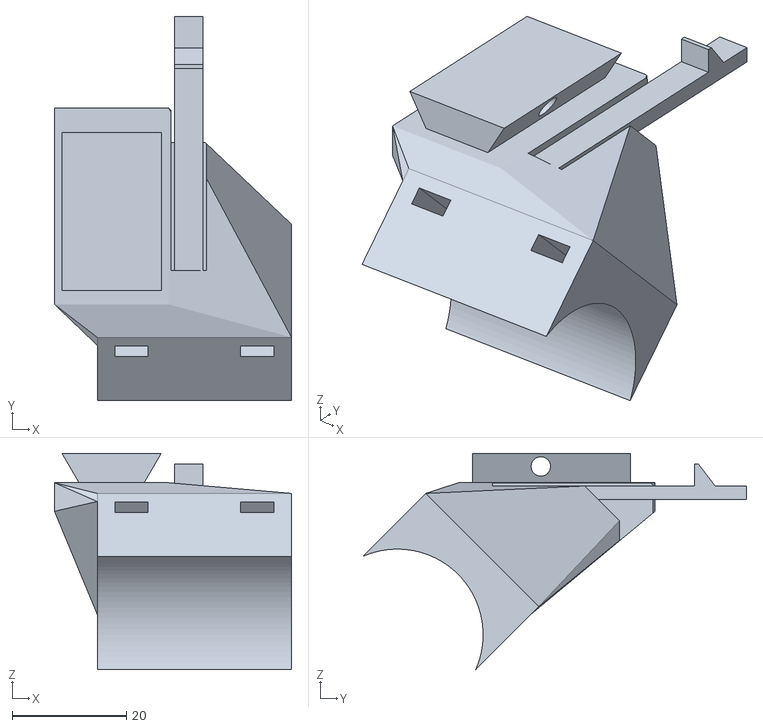
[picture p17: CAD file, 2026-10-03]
soporte/gps_base.stl
41.5 x 67.2 x 37.9

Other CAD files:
soporte/caja_169/caja169_base.stl
soporte/caja_169/caja169_modulo.stl
soporte/caja_169/caja169_tapa.stl

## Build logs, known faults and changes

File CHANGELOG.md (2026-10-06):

# Historial de cambios

## 3.2.0 – 2026-10-06

- Símbolo REC parpadeante arriba en el centro mientras se graba la ruta (sustituye al punto rojo).

## 3.1.0 – 2026-10-06

- Botonera externa de membrana de 2 botones en GPIO16, GPIO2 y GPIO3, con aprendizaje automático de los hilos.
- Amarillo: centro (breve) y calibración completa (3 s). Rojo: borrar máximos (breve) y terminar o reanudar ruta (1,5 s). Los dos: girar pantalla.
- Documentados los colores del conector de 12 hilos.

## 3.0.0 – 2026-10-04

Versión para la placa Waveshare ESP32-S3-LCD-1.69 (`firmware/moto_inclinometro_169`). Compila; sin probar en placa real.

- Pantalla de 240×280: número de inclinación más grande, sin velocidad.
- Fondo rojo parpadeante al pasar de 40°. Zona central de ±4° marcada como RECTA.
- Iconos de GPS (rojo parpadeante / verde) y WiFi (gris / verde).
- BOOT breve gira la pantalla; BOOT 3 s calibra en dos pasos; PWR breve ajusta el centro (solo si el desvío es menor de ±10°); PWR 1,5 s termina o reanuda la ruta.
- Los máximos se ponen a cero al empezar cada ruta.
- Página web `/ajustes` con calibración, ajuste de centro y giro de pantalla.

## 2.3.0 – 2026-10-03

- Terminar la ruta a mano: botón verde mantenido 1,5 s o enlace en la página de rutas. La misma acción reanuda la grabación.
- LED: corregidos el rojo y el verde, que salían intercambiados; azul cuando la grabación está parada a mano.

## 2.2.0 – 2026-10-03

- El LED de colores de la placa indica el estado del GPS: rojo, amarillo, verde y guiño al grabar.
- Tapas con una mirilla de 3,5 mm para ver ese LED.

## 2.1.0 – 2026-10-03

- Página `/gps` de diagnóstico: indica si el GPS contesta, con contadores, satélites y las últimas frases recibidas.
- Las frases del GPS salen también por el puerto serie USB (115200 baudios).

## 2.0.1 – 2026-10-03

- Tapas: ventana de pantalla 0,6 mm más ancha por el lado de los botones y por el opuesto, tras probar la tapa impresa.
- Tapas exportadas con la cara exterior hacia la cama, para que el rebaje interior salga limpio.
- Enlace de donación.

## 2.0.0 – 2026-10-03

Versión que reúne todo lo añadido desde la 0.2: GPS, rutas, web ampliada y caja desmontable.

Firmware:

- GPS NEO-6M: velocidad en pantalla (sustituye a la aceleración en directo) y velocidad máxima.
- Grabación automática de rutas en la memoria de la placa, un punto por segundo, con unas 19 horas de capacidad.
- Web: páginas de rutas (descarga en CSV y borrado) y de WiFi de casa; velocidad y estado del GPS en la página de inicio.
- Conexión opcional a la WiFi doméstica, con acceso por `http://motolean.local`.
- El número de versión aparece al arrancar y en la web.

Mapa:

- Página `mapa/index.html` para ver una ruta: trazado por inclinación o velocidad, marcas de frenadas y acelerones, resumen y tres fondos de mapa.

Cajas:

- Caja desmontable con GPS: base fija con carril en cola de milano y pestaña, módulo con placa, GPS y antena, y seguro opcional con tornillo M3.
- Pulsadores para la tapa, que sobresalen 3 mm.
- Tapas y huecos ajustados con medidas de calibre: botones cada 7,1 mm, pantalla a 0,5 mm de la tapa, apoyos para que la placa quede recta y ventana en bisel.

Documentación:

- Nuevos: `MATERIALES.md`, `WEB.md`, `GPS_Y_RUTAS.md` y `CAJA_GPS.md`.
- README reorganizado.

## 0.5.1 – 2026-10-03

- Las dos cajas: hueco de la placa de 9 a 7,45 mm para acercar la pantalla a la tapa, y apoyos para que la placa no quede torcida.
- Tapas con ventana en bisel y rebaje interior para los pulsadores; pulsadores con ala de 0,8 mm.

## 0.5.0 – 2026-10-03

- Caja desmontable con GPS: base fija con carril y pestaña, y módulo con placa, GPS y antena.
- Mapa: fondos de IGN y Esri.

## 0.4.0 – 2026-10-03

- GPS NEO-6M: velocidad en pantalla y velocidad máxima.
- Grabación de rutas en la memoria de la placa y descarga en CSV.
- Página `mapa/index.html` para ver la ruta sobre el mapa.
- Conexión opcional a la WiFi de casa (`http://motolean.local`).

## 0.3.0 – 2026-10-03

- Pulsadores para la tapa, que sobresalen 3 mm.
- Agujeros de la tapa reducidos a 5,0 mm para retener mejor los pulsadores.

## 0.2.1 – 2026-10-03

- Tapa del soporte corregida con medidas de calibre: botones cada 7,1 mm y ventana de 16,5 mm recentrada. El cuerpo no cambia.

## 0.2.0 – 2026-10-03

- Nueva pantalla: arco de inclinación con marcas de máximo y barras laterales de frenada y aceleración.
- Aceleración longitudinal en directo.
- Soporte de manillar a 45° para imprimir en 3D (cuerpo y tapa).
- Documentación del proyecto.

## 0.1.0 – 2026-10-03

- Primera versión: inclinación en directo, máximos a cada lado, máximos de aceleración y frenada.
- Calibración en dos pasos para cualquier posición de montaje.
- Máximos y calibración guardados en memoria.
- Página web para el móvil por WiFi propia.

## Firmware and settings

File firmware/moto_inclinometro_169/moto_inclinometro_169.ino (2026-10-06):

/*
  INCLINOMETRO PARA MOTO - Waveshare ESP32-S3-LCD-1.69 (pantalla de 240x280 + IMU QMI8658)

  Muestra: inclinacion en directo, maxima a izquierda y derecha, y maxima aceleracion y frenada (en g).
  Con un GPS NEO-6M graba las rutas (posicion, velocidad, inclinacion y g) para verlas en un mapa.
  Los maximos se ponen a cero al empezar cada ruta.

  BOTONES
    BOOT  pulsacion corta  -> girar la pantalla 180 grados
          mantener 3 s     -> calibracion completa (2 pasos: recta y apoyada en la pata)
    PWR   pulsacion corta  -> ajuste de centro: lo que marca pasa a ser 0 (solo con menos de 10 grados)
          mantener 1,5 s   -> terminar la ruta y parar la grabacion (otra vez: reanudar)

  PANTALLA
    Icono GPS (arriba izquierda): verde fijo con posicion, rojo parpadeando sin ella. REC parpadeando arriba en el centro = grabando.
    Icono WiFi (arriba derecha): verde con conexion, gris sin ella.
    Por encima de 40 grados el fondo parpadea en rojo. Por debajo de 4 grados marca RECTA.

  MOVIL: conectate a la WiFi "MotoLean" (clave moto1234) y abre http://192.168.4.1

  Libreria necesaria: TFT_eSPI, configurada con Setup_Waveshare_169.h (ver docs/PLACA_169.md).
*/

#include <TFT_eSPI.h>
#include <Wire.h>
#include <WiFi.h>
#include <WebServer.h>
#include <Preferences.h>
#include <LittleFS.h>
#include <ESPmDNS.h>
#include <time.h>

#define VERSION "3.2"

// ---------------- Ajustes ----------------
const char *WIFI_NOMBRE = "MotoLean";
const char *WIFI_CLAVE  = "moto1234";      // minimo 8 caracteres

#define PIN_SDA   11
#define PIN_SCL   10
#define PIN_BL    15
#define BTN_BOOT  0       // activo a nivel bajo
#define BTN_PWR   40      // SYS_OUT: a nivel alto mientras se pulsa
#define PIN_SYS_EN 41     // mantiene la alimentacion cuando va con bateria
#define PIN_ZUMB  42      // zumbador (sin uso)
#define IMU_ADDR  0x6B
// Botonera de membrana de 2 botones y 3 hilos. Los tres hilos van a tres pines, en cualquier orden:
// el programa aprende que hilos une cada boton, asi que no hace falta saber cual es el comun.
const uint8_t KB_PIN[3] = { 16, 2, 3 };

#define ANCHO 240
#define ALTO  280
const float ZONA_RECTA   = 4.0f;    // por debajo de esto la moto se considera recta
const float ANGULO_AVISO = 40.0f;   // a partir de aqui el fondo parpadea en rojo
const float CENTRO_MAX   = 10.0f;   // el ajuste de centro solo se acepta por debajo de esto

const float LEAN_MIN_REG = 8.0f;    // por debajo de esto no se registra como maximo
const float LEAN_MAX_REG = 70.0f;   // por encima se descarta (caida / lectura falsa)
const float G_MAX_REG    = 2.0f;    // aceleraciones mayores se descartan

// ---------------- Vectores ----------------
struct V3 { float x, y, z; };
static inline V3 vadd(V3 a, V3 b) { return { a.x + b.x, a.y + b.y, a.z + b.z }; }
static inline V3 vsub(V3 a, V3 b) { return { a.x - b.x, a.y - b.y, a.z - b.z }; }
static inline V3 vmul(V3 a, float k) { return { a.x * k, a.y * k, a.z * k }; }
static inline float vdot(V3 a, V3 b) { return a.x * b.x + a.y * b.y + a.z * b.z; }
static inline V3 vcross(V3 a, V3 b) { return { a.y * b.z - a.z * b.y, a.z * b.x - a.x * b.z, a.x * b.y - a.y * b.x }; }
static inline float vnorm(V3 a) { return sqrtf(vdot(a, a)); }
static inline V3 vunit(V3 a) { float n = vnorm(a); return n > 1e-6f ? vmul(a, 1.0f / n) : a; }

// ---------------- Estado ----------------
TFT_eSPI tft = TFT_eSPI();
TFT_eSprite spr = TFT_eSprite(&tft);
WebServer web(80);
Preferences nvs;

bool imuOk = false, calibrado = false;
V3 ejeArriba = { 0, 0, 1 }, ejeDelante = { 1, 0, 0 }, ejeIzq = { 0, 1, 0 };
V3 biasGiro = { 0, 0, 0 };
V3 accF = { 0, 0, 1 };          // acelerometro filtrado
float guinoF = 0;               // giro "no de balanceo" filtrado (para saber si va recto)

float lean = 0;                 // grados, positivo = derecha
float accLong = 0;              // g, positivo = acelerando
float maxIzq = 0, maxDer = 0, maxAcel = 0, maxFren = 0, maxVel = 0;
bool hayQueGuardar = false;
uint32_t tUltimoGuardado = 0;
uint8_t rotacion = 0;

// ---------------- Botones ----------------
// ---------------- Botonera externa ----------------
uint8_t kbPar[2] = { 255, 255 };      // par de hilos de cada boton (0..2); 255 = sin configurar
uint32_t kbTDos = 0;
// Devuelve una mascara con los pares de hilos que estan unidos: bit0 = 0-1, bit1 = 0-2, bit2 = 1-2
uint8_t kbLee() {
  static const uint8_t A[3] = { 0, 0, 1 }, B[3] = { 1, 2, 2 };
  uint8_t m = 0;
  for (uint8_t i = 0; i < 3; i++) {
    pinMode(KB_PIN[A[i]], OUTPUT); digitalWrite(KB_PIN[A[i]], LOW);
    delayMicroseconds(40);
    if (digitalRead(KB_PIN[B[i]]) == LOW) m |= 1 << i;
    pinMode(KB_PIN[A[i]], INPUT_PULLUP);
    delayMicroseconds(40);
  }
  return m;
}

struct Boton {
  uint8_t pin; uint16_t msLargo; bool activoAlto;
  bool antes = false, largoHecho = false; uint32_t t0 = 0;
  bool corta = false, larga = false;
  int8_t kb = -1;                     // -1: boton de la placa; 0 amarillo, 1 rojo, 2 los dos a la vez
  Boton(uint8_t p, uint16_t ms, bool alto = false) : pin(p), msLargo(ms), activoAlto(alto) {}
  Boton(int8_t k, uint16_t ms, int) : pin(0), msLargo(ms), activoAlto(false), kb(k) {}
  void begin() { if (kb < 0) pinMode(pin, activoAlto ? INPUT : INPUT_PULLUP); antes = pulsado(); largoHecho = antes; }
  bool pulsado() {
    if (kb < 0) return digitalRead(pin) == (activoAlto ? HIGH : LOW);
    uint8_t m = kbLee();
    bool dos = (m & (m - 1)) != 0;    // mas de un par unido: los dos botones
    if (dos) kbTDos = millis();
    if (kb == 2) return dos;
    if (dos || kbPar[kb] > 2) return false;
    return m == (1 << kbPar[kb]);
  }
  void leer() {
    corta = larga = false;
    bool ahora = pulsado();
    uint32_t t = millis();
    if (ahora && !antes) { t0 = t; largoHecho = false; }
    if (ahora && !largoHecho && t - t0 > msLargo) { larga = true; largoHecho = true; }
    if (!ahora && antes && !largoHecho && t - t0 > 30) corta = true;
    if (kb >= 0 && kb < 2 && t - kbTDos < 700) corta = larga = false;   // se estaban soltando los dos
    antes = ahora;
  }
};
Boton bBoot(BTN_BOOT, 3000), bPwr(BTN_PWR, 1500, true);
Boton bAma((int8_t)0, 3000, 0), bRojo((int8_t)1, 1500, 0), bDos((int8_t)2, 1500, 0);

// ---------------- IMU QMI8658 ----------------
void imuEscribe(uint8_t reg, uint8_t val) {
  Wire.beginTransmission((uint8_t)IMU_ADDR);
  Wire.write(reg); Wire.write(val);
  Wire.endTransmission();
}

bool imuInicia() {
  Wire.beginTransmission((uint8_t)IMU_ADDR);
  Wire.write(0x00);
  if (Wire.endTransmission(false) != 0) return false;
  if (Wire.requestFrom((uint8_t)IMU_ADDR, (uint8_t)1) != 1) return false;
  if (Wire.read() != 0x05) return false;      // WHO_AM_I
  imuEscribe(0x60, 0xB0); delay(20);          // reinicio
  imuEscribe(0x02, 0x40);                     // auto-incremento, little-endian
  imuEscribe(0x03, 0x25);                     // acelerometro +-8 g, 235 Hz
  imuEscribe(0x04, 0x55);                     // giroscopio +-512 grados/s, 235 Hz
  imuEscribe(0x06, 0x11);                     // filtros paso bajo activados
  imuEscribe(0x08, 0x03);                     // encender acelerometro + giroscopio
  delay(50);
  return true;
}

// a en g, g en grados/segundo
bool imuLee(V3 &a, V3 &g) {
  Wire.beginTransmission((uint8_t)IMU_ADDR);
  Wire.write(0x35);
  if (Wire.endTransmission(false) != 0) return false;
  if (Wire.requestFrom((uint8_t)IMU_ADDR, (uint8_t)12) != 12) return false;
  int16_t r[6];
  for (int i = 0; i < 6; i++) {
    uint8_t lo = Wire.read(), hi = Wire.read();
    r[i] = (int16_t)(lo | (hi << 8));
  }
  a = { r[0] / 4096.0f, r[1] / 4096.0f, r[2] / 4096.0f };
  g = { r[3] / 64.0f, r[4] / 64.0f, r[5] / 64.0f };
  return true;
}

// Media durante "ms". Devuelve cuanto se ha movido el giroscopio (para saber si estaba quieta)
float imuMedia(uint16_t ms, V3 &aM, V3 &gM) {
  V3 sa = { 0, 0, 0 }, sg = { 0, 0, 0 }, a, g, gMin = { 1e9, 1e9, 1e9 }, gMax = { -1e9, -1e9, -1e9 };
  int n = 0;
  uint32_t t0 = millis();
  while (millis() - t0 < ms) {
    if (imuLee(a, g)) {
      sa = vadd(sa, a); sg = vadd(sg, g); n++;
      gMin = { min(gMin.x, g.x), min(gMin.y, g.y), min(gMin.z, g.z) };
      gMax = { max(gMax.x, g.x), max(gMax.y, g.y), max(gMax.z, g.z) };
    }
    delay(5);
  }
  if (n == 0) return 1e9;
  aM = vmul(sa, 1.0f / n); gM = vmul(sg, 1.0f / n);
  return vnorm(vsub(gMax, gMin));
}

// ---------------- Memoria ----------------
void guardaV3(const char *k, V3 v) { nvs.putBytes(k, &v, sizeof(V3)); }
V3 leeV3(const char *k, V3 def) { V3 v = def; nvs.getBytes(k, &v, sizeof(V3)); return v; }

void guardaMaximos() {
  nvs.putFloat("mIzq", maxIzq); nvs.putFloat("mDer", maxDer);
  nvs.putFloat("mAce", maxAcel); nvs.putFloat("mFre", maxFren);
  nvs.putFloat("mVel", maxVel);
  hayQueGuardar = false; tUltimoGuardado = millis();
}

void borraMaximos() {
  maxIzq = maxDer = maxAcel = maxFren = maxVel = 0;
  guardaMaximos();
}

void cargaTodo() {
  calibrado = nvs.getBool("cal", false);
  ejeArriba = leeV3("up", ejeArriba);
  ejeDelante = leeV3("fwd", ejeDelante);
  ejeIzq = leeV3("izq", ejeIzq);
  biasGiro = leeV3("bias", biasGiro);
  maxIzq = nvs.getFloat("mIzq", 0); maxDer = nvs.getFloat("mDer", 0);
  maxAcel = nvs.getFloat("mAce", 0); maxFren = nvs.getFloat("mFre", 0);
  maxVel = nvs.getFloat("mVel", 0);
  rotacion = nvs.getUChar("rot", 0);
}

// ---------------- GPS (NEO-6M, modulo GY-GPS6MV2) ----------------
// Cableado: VCC->5V (o 3V3), GND->GND, TX del GPS->GPIO17, RX del GPS->GPIO18
#define GPS_RX 17
#define GPS_TX 18

bool gpsFix = false, gpsNueva = false;
uint32_t gpsUltimo = 0;          // millis() de la ultima posicion valida
double gpsLat = 0, gpsLon = 0;
float gpsKmh = 0;
uint32_t gpsUnix = 0;            // hora UTC en segundos desde 1970
char nmea[100];
uint8_t nmeaN = 0;
// Diagnostico: lo que llega del GPS, para verlo en /gps y por el puerto serie
uint32_t gpsBytes = 0, gpsFrases = 0, gpsMalas = 0;
int gpsSat = -1;
char gpsUltimas[6][84];
uint8_t gpsUltN = 0;

double nmeaCoord(const char *v, const char *h) {
  if (!*v) return 0;
  double x = atof(v);
  int grados = (int)(x / 100);
  double r = grados + (x - grados * 100) / 60.0;
  return (*h == 'S' || *h == 'W') ? -r : r;
}

uint32_t aUnix(int y, int m, int d, int hh, int mm, int ss) {
  y -= m <= 2;
  long era = y / 400;
  unsigned yoe = y - era * 400;
  unsigned doy = (153 * (m + (m > 2 ? -3 : 9)) + 2) / 5 + d - 1;
  unsigned doe = yoe * 365 + yoe / 4 - yoe / 100 + doy;
  long dias = era * 146097L + (long)doe - 719468L;
  return (uint32_t)dias * 86400UL + hh * 3600UL + mm * 60UL + ss;
}

static int dosDig(const char *c) { return (c[0] - '0') * 10 + (c[1] - '0'); }

// Solo se usa la frase RMC: hora, posicion, velocidad y fecha
void nmeaProcesa(char *l) {
  char *ast = strchr(l, '*');
  if (!ast) return;
  uint8_t cs = 0;
  for (char *q = l + 1; q < ast; q++) cs ^= (uint8_t)*q;
  if (cs != (uint8_t)strtol(ast + 1, NULL, 16)) { gpsMalas++; return; }
  gpsFrases++;
  strlcpy(gpsUltimas[gpsUltN % 6], l, sizeof(gpsUltimas[0])); gpsUltN++;
  Serial.println(l);                       // eco al puerto serie USB (115200)
  *ast = 0;
  if (strlen(l) >= 6 && strncmp(l + 3, "GGA", 3) == 0) {   // numero de satelites
    int coma = 0;
    for (char *q = l; *q; q++) if (*q == ',' && ++coma == 7) { gpsSat = atoi(q + 1); break; }
    return;
  }
  if (strlen(l) < 6 || strncmp(l + 3, "RMC", 3) != 0) return;

  char *c[14]; int n = 0;
  c[n++] = l;
  for (char *q = l; *q && n < 14; q++) if (*q == ',') { *q = 0; c[n++] = q + 1; }
  if (n < 10) return;
  if (c[2][0] != 'A') { gpsFix = false; return; }
  if (strlen(c[1]) < 6 || strlen(c[9]) < 6) return;

  gpsLat = nmeaCoord(c[3], c[4]);
  gpsLon = nmeaCoord(c[5], c[6]);
  gpsKmh = atof(c[7]) * 1.852f;
  gpsUnix = aUnix(2000 + dosDig(c[9] + 4), dosDig(c[9] + 2), dosDig(c[9]),
                  dosDig(c[1]), dosDig(c[1] + 2), dosDig(c[1] + 4));
  gpsFix = true; gpsNueva = true; gpsUltimo = millis();
  if (gpsKmh > maxVel + 0.5f && gpsKmh < 300) { maxVel = gpsKmh; hayQueGuardar = true; }
}

void gpsLee() {
  while (Serial1.available()) {
    char ch = Serial1.read();
    gpsBytes++;
    if (ch == '$') nmeaN = 0;
    if (ch == '\r' || ch == '\n') {
      if (nmeaN > 6) { nmea[nmeaN] = 0; nmeaProcesa(nmea); }
      nmeaN = 0;
    } else if (nmeaN < sizeof(nmea) - 1) nmea[nmeaN++] = ch;
  }
  if (gpsFix && millis() - gpsUltimo > 3000) gpsFix = false;
}

// ---------------- Grabacion de rutas ----------------
// Un registro por segundo, 20 bytes. En los 9,9 MB de esta placa caben mas de 100 horas en movimiento.
struct __attribute__((packed)) Reg {
  uint32_t t;            // hora UTC (segundos desde 1970)
  int32_t lat, lon;      // grados x 1e7
  uint16_t v;            // km/h x 100
  int16_t lean;          // grados x 10: la mayor inclinacion del segundo (+ derecha)
  int16_t aMax, aMin;    // g x 1000: mayor aceleracion y mayor frenada del segundo
};

bool fsOk = false, grabando = false;
bool rutaPausa = false;      // grabacion parada a mano (boton PWR largo o web) hasta reanudarla o apagar
fs::File fRuta;
char nombreRuta[40] = "";
uint8_t sinVolcar = 0, parado = 0;
float sLean = 0, sAMax = 0, sAMin = 0;      // picos del segundo en curso

// Borra la ruta mas antigua mientras falte sitio
void haceSitio() {
  for (int i = 0; i < 20 && LittleFS.totalBytes() - LittleFS.usedBytes() < 60000; i++) {
    String viejo = "";
    fs::File d = LittleFS.open("/");
    for (fs::File f = d.openNextFile(); f; f = d.openNextFile()) {
      String nom = String("/") + f.name();
      if (nom.startsWith("/r_") && nom != nombreRuta && (viejo == "" || nom < viejo)) viejo = nom;
    }
    if (viejo == "") return;
    LittleFS.remove(viejo);
  }
}

// Cierra la ruta en curso y la deja guardada
void terminaRuta() {
  if (!grabando) return;
  fRuta.close();
  grabando = false; nombreRuta[0] = 0; sinVolcar = 0;
}

void registra() {
  gpsNueva = false;
  if (!fsOk) return;
  if (!grabando) {
    if (rutaPausa || gpsKmh < 5) return;                 // la ruta empieza al echar a andar
    haceSitio();
    borraMaximos();                         // los maximos son de cada ruta
    time_t tt = gpsUnix; struct tm *g = gmtime(&tt);
    snprintf(nombreRuta, sizeof(nombreRuta), "/r_%04d%02d%02d_%02d%02d%02d.bin",
             g->tm_year + 1900, g->tm_mon + 1, g->tm_mday, g->tm_hour, g->tm_min, g->tm_sec);
    fRuta = LittleFS.open(nombreRuta, "w");
    if (!fRuta) { nombreRuta[0] = 0; return; }
    grabando = true; parado = 0;
  }
  // Parado mas de 5 s: no se gastan registros
  if (gpsKmh < 3) { if (parado < 255) parado++; } else parado = 0;
  if (parado <= 5) {
    Reg r;
    r.t = gpsUnix;
    r.lat = (int32_t)llround(gpsLat * 1e7); r.lon = (int32_t)llround(gpsLon * 1e7);
    r.v = (uint16_t)constrain(gpsKmh * 100.0f, 0.0f, 65000.0f);
    r.lean = (int16_t)lroundf(sLean * 10);
    r.aMax = (int16_t)lroundf(constrain(sAMax, -3.0f, 3.0f) * 1000);
    r.aMin = (int16_t)lroundf(constrain(sAMin, -3.0f, 3.0f) * 1000);
    fRuta.write((uint8_t *)&r, sizeof(r));
    if (++sinVolcar >= 10) { fRuta.flush(); sinVolcar = 0; haceSitio(); }
  }
  sLean = lean; sAMax = sAMin = accLong;
}

// ---------------- Pantalla ----------------
#define C_GRIS   0x31A7   // gris oscuro (fondo de arco y barras)
#define C_GRISC  0x8C92   // gris claro (rotulos)
#define C_AZUL   0x2C7F
#define C_AMAR   0xFE80
#define C_ROJO   0xF985
#define C_VERDE  0x3EEB
#define C_NAR    0xFC60
#define C_CIAN   0x06FF
#define C_AVISO  0x9000   // rojo oscuro del fondo de aviso

uint16_t cFondo = TFT_BLACK;
String wifiCasa = "", claveCasa = "";
bool casaBuscando = false, casaConectada = false;

void mensaje(const char *l1, const char *l2 = "", const char *l3 = "", const char *l4 = "", uint16_t color = TFT_YELLOW) {
  spr.fillSprite(TFT_BLACK);
  spr.setTextDatum(MC_DATUM);
  spr.setTextColor(color);
  spr.drawString(l1, ANCHO / 2, 62, 4);
  spr.setTextColor(TFT_WHITE);
  spr.drawString(l2, ANCHO / 2, 122, 4);
  spr.drawString(l3, ANCHO / 2, 156, 4);
  spr.setTextColor(TFT_ORANGE);
  spr.drawString(l4, ANCHO / 2, 226, 4);
  spr.pushSprite(0, 0);
}

// Marca radial sobre el arco. "grados" desde la vertical, + = derecha
void marca(float grados, int rExt, int rInt, float ancho, uint16_t color) {
  float a = grados * DEG_TO_RAD, s = sinf(a), c = cosf(a);
  spr.drawWideLine(120 + rExt * s, 150 - rExt * c, 120 + rInt * s, 150 - rInt * c, ancho, color, cFondo);
}

// Barra vertical de 10 segmentos (0,1 g cada uno) con raya de maximo
void barra(int x, float val, float maxi, uint16_t color, uint16_t gris) {
  int n = (int)lroundf(constrain(val, 0.0f, 1.0f) * 10);
  for (int i = 0; i < 10; i++)
    spr.fillRect(x, 70 + i * 13, 13, 10, (9 - i) < n ? color : gris);
  int ym = 200 - (int)(constrain(maxi, 0.0f, 1.0f) * 130);
  spr.fillRect(x - 3, ym - 2, 19, 3, TFT_WHITE);
}

// Simbolo de grados: un aro
void grado(int x, int y, int r, int grosor, uint16_t color) {
  spr.fillCircle(x, y, r, color);
  spr.fillCircle(x, y, r - grosor, cFondo);
}

void iconoGps(int x, int y, uint16_t c) {
  spr.fillCircle(x, y - 2, 9, c);
  spr.fillTriangle(x - 7, y + 3, x + 7, y + 3, x, y + 15, c);
  spr.fillCircle(x, y - 2, 3, cFondo);
}

void iconoWifi(int x, int y, uint16_t c) {
  spr.drawSmoothArc(x, y + 8, 17, 14, 135, 225, c, cFondo, true);
  spr.drawSmoothArc(x, y + 8, 11, 8, 135, 225, c, cFondo, true);
  spr.fillCircle(x, y + 7, 3, c);
}
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
void loop() {
  static uint32_t tAnt = micros(), tDib = 0;
  V3 a, g;
  if (imuLee(a, g)) {
    uint32_t t = micros();
    float dt = (t - tAnt) * 1e-6f;
    tAnt = t;
    if (dt > 0 && dt < 0.1f) calcula(dt, a, g);
  }

  bBoot.leer(); bPwr.leer();
  if (bBoot.larga) { calibrar(); tAnt = micros(); }
  if (bBoot.corta) giraPantalla();
  bAma.leer(); bRojo.leer(); bDos.leer();
  if (kbPar[0] > 2 && kbLee()) { kbAprende(); tAnt = micros(); }   // primera pulsacion: configurar la botonera
  if (bAma.larga) { calibrar(); tAnt = micros(); }
  if (bDos.larga) giraPantalla();
  if (bRojo.corta) {
    borraMaximos();
    mensaje("MAXIMOS", "borrados", "", "", TFT_GREEN);
    delay(800); tAnt = micros();
  }
  if (bPwr.corta || bAma.corta) {           // ajuste de centro
    if (ajustaCentro()) mensaje("CENTRO", "ajustado", "ahora marca 0", "", TFT_GREEN);
    else mensaje("CENTRO", "no ajustado", "mas de 10 grados", "", TFT_RED);
    delay(1000); tAnt = micros();
  }
  if (bPwr.larga || bRojo.larga) {                         // parar / reanudar la grabacion de rutas
    rutaPausa = !rutaPausa;
    if (rutaPausa) terminaRuta();
    if (rutaPausa) mensaje("RUTA", "terminada", "y guardada", "ROJO 1,5 s: reanudar", TFT_GREEN);
    else mensaje("RUTA", "grabacion", "activada", "", TFT_GREEN);
    delay(1200); tAnt = micros();
  }

  gpsLee();
  if (gpsNueva) registra();

  web.handleClient();
  wifiCasaVigila();

  uint32_t ms = millis();
  if (ms - tDib > 70) {
    tDib = ms;
    if (calibrado) dibuja();
    else mensaje("SIN CALIBRAR", "Manten BOOT 3 s", "para calibrar");
  }
  // Guardado automatico (como mucho cada 5 s, y solo si ha cambiado algun maximo)
  if (hayQueGuardar && ms - tUltimoGuardado > 5000) guardaMaximos();

  delay(3);
}

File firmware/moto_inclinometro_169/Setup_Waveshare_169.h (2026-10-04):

// Configuracion de TFT_eSPI para la Waveshare ESP32-S3-LCD-1.69 (ST7789V2, 240x280)
// Copiar a la carpeta User_Setups de la libreria y seleccionarlo en User_Setup_Select.h
#define USER_SETUP_ID 469
#define USE_HSPI_PORT
#define ST7789_DRIVER
#define TFT_WIDTH  240
#define TFT_HEIGHT 280
#define CGRAM_OFFSET
#define TFT_RGB_ORDER TFT_RGB
#define TFT_INVERSION_ON
#define TFT_BACKLIGHT_ON 1

#define TFT_BL   15
#define TFT_MISO -1
#define TFT_MOSI 7
#define TFT_SCLK 6
#define TFT_CS   5
#define TFT_DC   4
#define TFT_RST  8

#define LOAD_GLCD
#define LOAD_FONT2
#define LOAD_FONT4
#define LOAD_FONT6
#define LOAD_FONT8
#define LOAD_GFXFF
#define SMOOTH_FONT

#define SPI_FREQUENCY       40000000
#define SPI_READ_FREQUENCY  20000000

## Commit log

2026-10-03 Inclinómetro para moto: firmware, soporte 3D y documentación
    Firmware para LOLIN S3 Mini Pro con inclinación, máximos y aceleración,
    binario listo para grabar, STL del soporte de manillar y documentación
    de carga, uso, montaje y compilación.
    Claude-Session: https://claude.ai/code/session_01DoHUXaoJBwacrVjXvgwcFQ
    [soporte_cuerpo.stl, soporte_tapa.stl]
2026-10-03 README: pantalla nueva probada en la placa
    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
2026-10-03 Docs: indicar que el soporte usa la medida de manillar calculada
    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
2026-10-03 Update support design status in README
    Removed note about printing the support design.
2026-10-03 Soporte: tapa corregida con medidas de calibre
    Botones cada 7,1 mm centrados en la placa y ventana de 16,5 mm
    recentrada sobre el cristal. El cuerpo no cambia.
    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
    [soporte_tapa.stl]
2026-10-03 Soporte: pulsadores para la tapa
    Tres pulsadores en forma de seta que sobresalen 3 mm, calculados con
    el hueco medido de 1,92 mm. Agujeros de la tapa reducidos a 5,0 mm.
    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
    [soporte_pulsador.stl, soporte_pulsadores_x3.stl, soporte_tapa.stl]
2026-10-03 GPS, grabación de rutas, mapa y WiFi de casa
    Lectura de un GPS NEO-6M (velocidad y posición), registro de la ruta
    en LittleFS con descarga en CSV, página de mapa y conexión opcional a
    la WiFi doméstica con mDNS.
    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
    [ruta_de_ejemplo.csv]
2026-10-03 Mapa: usar el fondo de CARTO en lugar del servidor de OpenStreetMap
    El servidor de teselas de OSM devuelve 403 al abrir la página desde
    un archivo local (sin Referer).
    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
2026-10-03 Mapa: fondos de IGN y Esri con selector de capas
    CARTO exige ahora clave de API.
    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
2026-10-03 Caja desmontable con GPS: base, módulo y tapa
    Base fija al manillar con carril en cola de milano y pestaña de cierre;
    módulo extraíble con huecos para la placa, el GPS y la antena.
    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
    [gps_base.stl, gps_modulo.stl, gps_tapa.stl]
2026-10-03 Cajas: pantalla más cerca de la tapa y placa apoyada recta
    Hueco de la placa de 9 a 7,45 mm según las alturas medidas (USB 3,35,
    cristal 1,85, botón 1,55/2,03), apoyos en el extremo de la pantalla,
    ventana en bisel y pulsadores adaptados.
    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
    [gps_modulo.stl, gps_tapa.stl, soporte_cuerpo.stl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]
2026-10-03 Docs: lámina con las piezas a imprimir de la caja con GPS
    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
2026-10-03 Versión 2.0
    GPS, grabación de rutas, mapa, web ampliada, WiFi de casa y caja
    desmontable. README reorganizado, lista de materiales y guía de la web.
    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
2026-10-03 Añadir enlace de donación (PayPal.me)
    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
2026-10-03 Tapas: ventana 0,6 mm más ancha por los dos lados marcados
    Y exportación con la cara exterior hacia la cama, para que el rebaje
    interior de los pulsadores no se imprima en voladizo.
    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
    [gps_tapa.stl, soporte_tapa.stl]
2026-10-03 Diagnóstico del GPS: página /gps y eco por el puerto serie USB (2.1)
    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
2026-10-03 LED de estado del GPS y mirilla en las tapas (2.2)
    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
    [gps_tapa.stl, soporte_tapa.stl]
2026-10-03 Docs: corregir la posición de la mirilla del LED
    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
2026-10-03 Terminar la ruta con el botón verde y corregir los colores del LED (2.3)
    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
2026-10-04 Propuesta de pantalla para la Waveshare ESP32-S3-LCD-1.69 (240x280)
    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
2026-10-04 Propuesta de pantalla 1.69: sin velocidad, iconos de GPS y WiFi, aviso rojo a 40°
    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
2026-10-04 Firmware 3.0 para Waveshare ESP32-S3-LCD-1.69
    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
2026-10-06 Firmware 3.1: botonera externa de 2 botones y colores del conector
    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
2026-10-06 Caja desmontable para la placa de 1,69 con GPS y botonera (STL y STEP)
    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
    [caja169_base.step, caja169_base.stl, caja169_conjunto.step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]
2026-10-06 Caja 1,69: mallas STL cerradas
    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
    [caja169_base.step, caja169_base.stl, caja169_conjunto.step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]
2026-10-11 Versión 3.2.1: sin PSRAM y aviso de calibrar con el amarillo
    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
